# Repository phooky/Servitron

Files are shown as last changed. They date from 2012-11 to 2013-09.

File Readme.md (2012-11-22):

Servitron Six
=============

Servitron Six is a six-axis DC servo control board initially developed to support PUMA robot arms and their cousins. It presumes that each servo consists of a DC gearmotor, a quadrature encoder, and optionally an index channel. It uses a BeagleBone A5 or greater to control the system and is designed so that your application can run directly on the BeagleBone.

It has not yet been tested with the new BeagleBone Black.

Hardware
--------

The board is designed to run off a 24V power supply. A switching supply provides 5V to the logic chips and the BeagleBone. Each servo channel is driven by a VNH3SP30 which can provide a peak of ~20A.

The hardware design files are in the "electronics/six_axis_board" directory. The hardware is licenced under the CERN Open Hardware License v1.1.

Software
--------

The software which runs on the BeagleBone is in the "servitron" directory.

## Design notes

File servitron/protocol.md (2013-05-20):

Servitron client-server protocol
================================

Server responsibilities:
* Track quadrature encoders
* Maintain information about position and velocity of all axes
* Execute positioning/velocity commands
* Maintain PID loops and current position
* Maintain brake

Types of interaction
--------------------

* Hello: client should connect to server and get a greeting message including server version
* Status: client can request status from the server and get current positions, speeds, and queue status.
* Calibration: set PID settings, find index pulse, confirm directionality, find physical range
* Configuration persistence.
* Non-blocking motion commands: clients should be able to place motions on a queue of sequentially interpreted commands

General command/response framework
----------------------------------

Most commands are fixed-length and determined by a simple struct. Commands begin with a one-byte command identifier.
Responses are also generally fixed-length and delivered as soon as possible. They begin with a one-byte response code.

All command-response transactions are sequential; a second command should not be sent before a reply is received unless the response has timed out. Responses delivered more than half a second after the command is sent are considered to have timed out.

Any command or response that is not fixed-length must end in a zero-terminated string.

Response codes
--------------
0x80 - OK
0x81 - generic error

Hello interaction
-----------------

The HELLO interaction is generally sent when a client connects. It is not required.

Command code: 0x01
Command payload:
    uint16_t clientVersion;
    char* clientString;

Response payload:
    uint16_t serverVersion;
    char* serverString;

Status interactions
-------------------

*Mechanical status*
Command code: 0x02
Command payload: None
Response payload:
    {
        int32_t position
        int32_t velocity
        uint8_t flags _axis enabled, axis calibrated, etc_
    }[6]
    uint8_t flags _brake enabled, system initialized_

*Queue status*
Command code: 0x03
Command payload: None
Response payload:
    int16_t remainingMoves

Calibration interactions
------------------------
Calibration and configuration commands begin at 0x10

*Find directionality*
Command code: 0x10
Command payload:
    uint8_t axis
Response payload:
    uint8_t directionality
Directionality response:
* 0x00: directionality is positive (+motor is +pos)
* 0x01: directionality is negative (+motor is -pos)
* 0x02: directionality seek failed (unable to move motor within window)

*Start range of motion seek*
Command code: 0x11
Command payload:
    uint8_t axis
Response payload: None

*Complete range of motion seek*
Command code: 0x12
Command payload: None
Response payload:
    int32_t min_pos
    int32_t max_pos
    // index pulse frequency information??? TODO

*Set PID*
Command code: 0x13
Command payload: 
    uint8_t axis
    // PID data??? TODO
Response payload: None

Persistence interactions
------------------------

*Load config*

*Save config*

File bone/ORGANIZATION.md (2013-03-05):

Yeah, clearly a cleanup is in order. 

Pinmuxing should be centralized, naming should be fixed...

Runtime organization.

Two components: userspace and PRU.

PRU: records quadrature; emits events.

SHOULD: pop out reports, eat settings?

let's do all motor control in userspace for now; we're not going to
beat that speed anyway

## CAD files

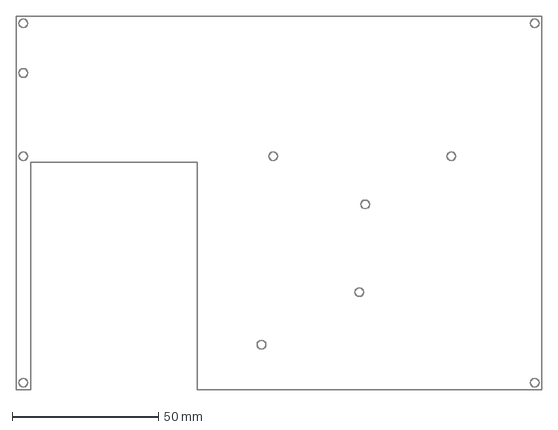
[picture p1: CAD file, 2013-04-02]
electronics/six_axis_board/mounting.dxf
180.0 x 128.0 mm

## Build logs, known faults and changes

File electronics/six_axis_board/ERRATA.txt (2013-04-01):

Version Zero
------------

- The brake transistor is turned on at startup. The bone needs to be initialized properly (appears to be pulling pin low).
- R43 needs to be below 1K to turn on the transistor fully. Not sure what's going on here.
- The brake circuit should be reworked completely.

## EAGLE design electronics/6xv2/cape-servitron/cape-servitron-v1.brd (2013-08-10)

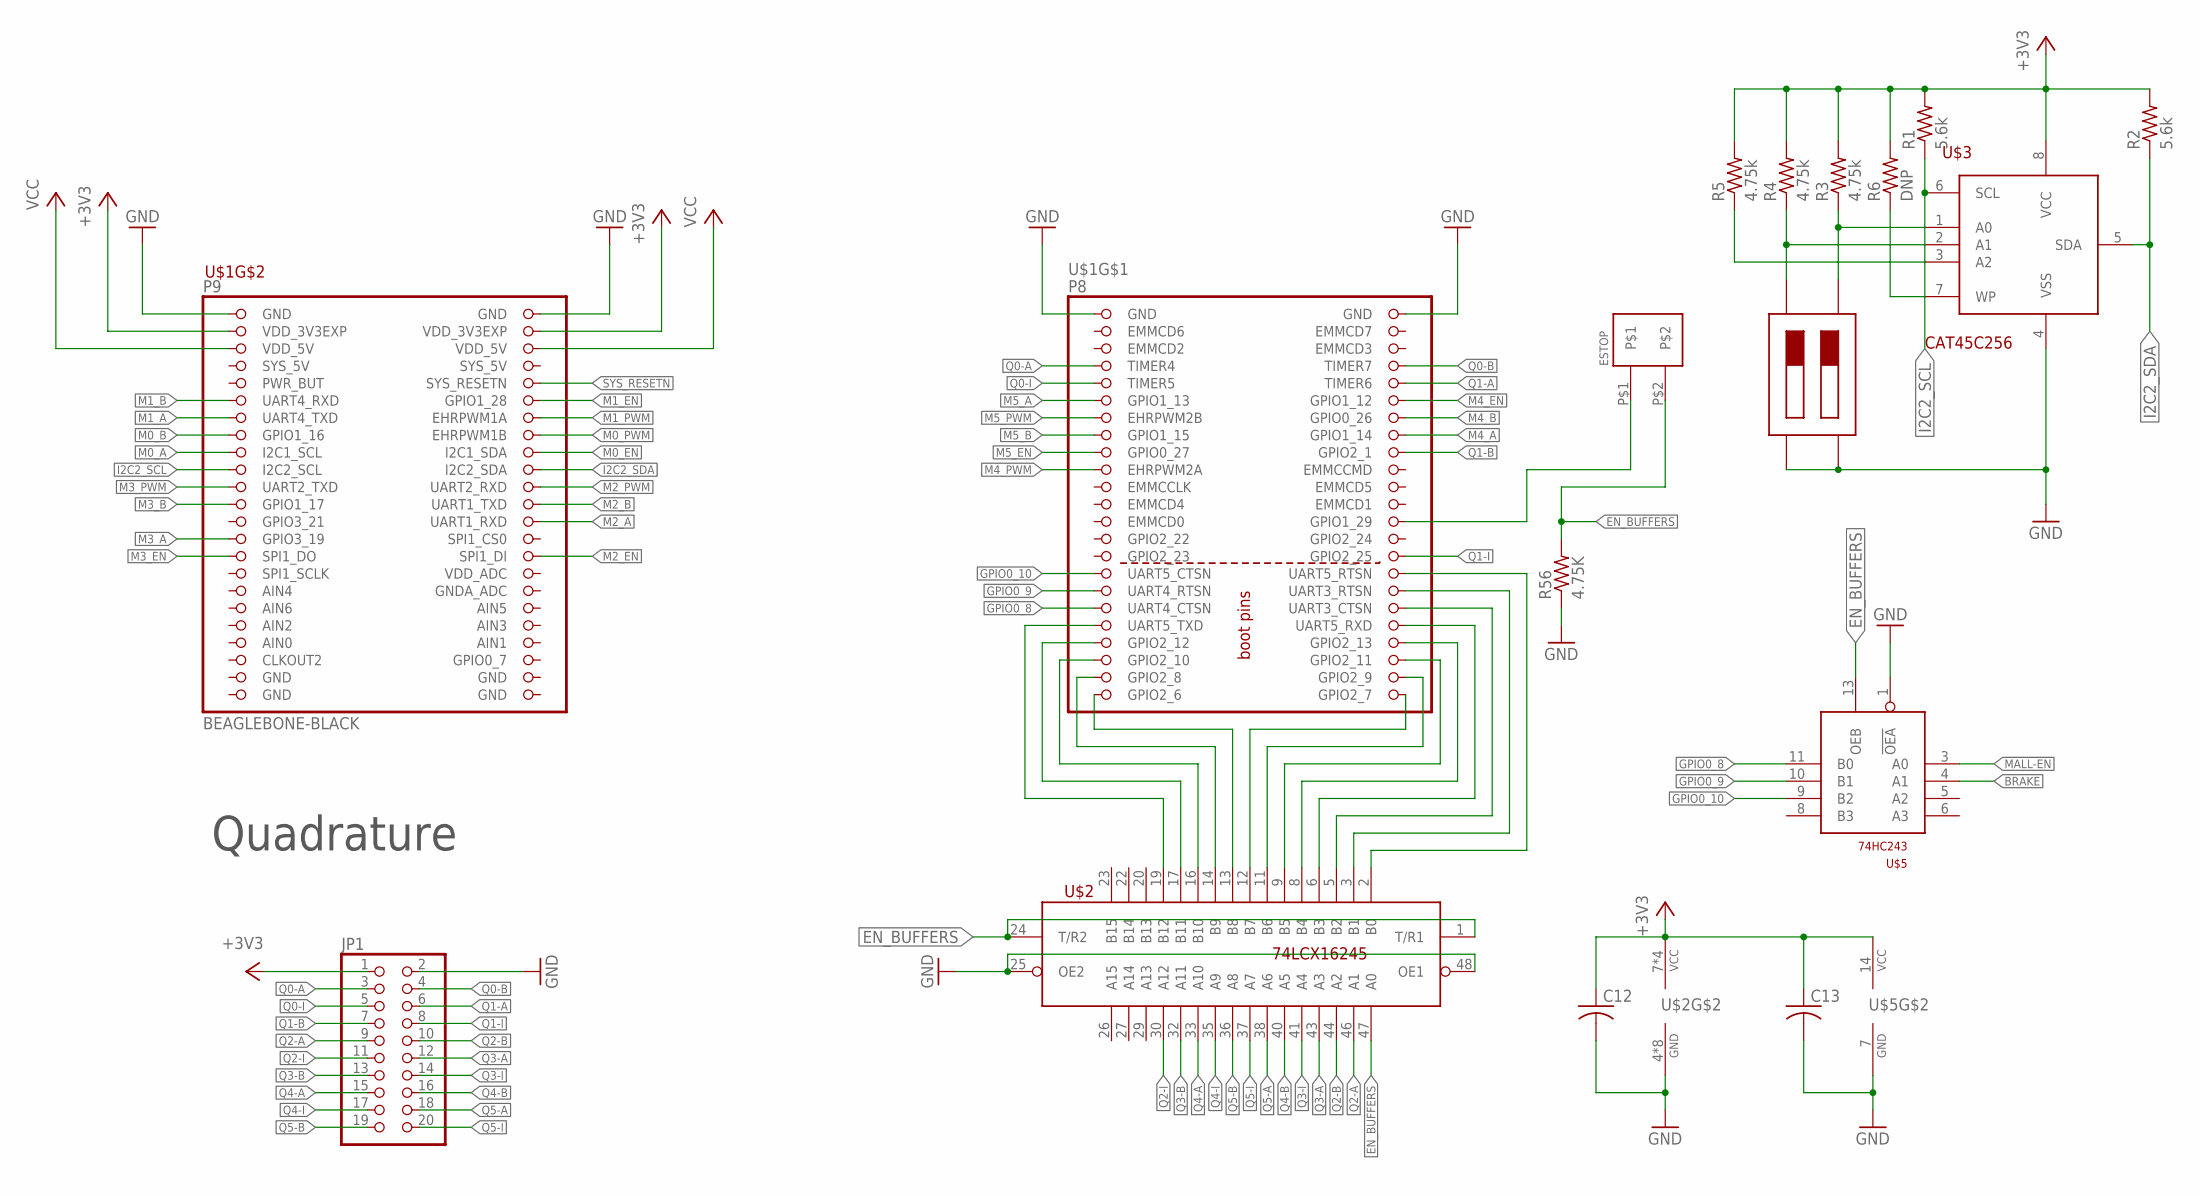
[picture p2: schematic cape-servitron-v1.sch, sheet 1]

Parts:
C12, C13: C-USC0805; C0805
ESTOP: PINHEAD-5MM-1X2; 5MM-HEADER-2
JP1: PINHD-2X10; 2X10
R1, R2: 5.6k; R0805
R3, R4, R5: 4.75k; R0805
R6: DNP; R0805
R56: 4.75K; R0805
U$1: BEAGLEBONE-BLACK; BEAGLEBONE_SHIELD
U$2: 74LCX16245; TSSOP-48
U$3: CAT24C2256Y; TSSOP-8
U$4: DIP-SW-2; CT219-2
U$5: 74HC243D; SO14

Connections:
!MALL-EN: U$5.3 (A0); also elsewhere on the board
+3V3: C12.1, C13.1, JP1.1, R1.2, R2.2, R3.2, R4.2, R5.2, R6.2, U$1.49 (VDD_3V3EXP), U$1.50 (VDD_3V3EXP), U$2.7 (VCC), U$2.18 (VCC), U$2.31 (VCC), U$2.42 (VCC), U$3.8 (VCC), U$5.14 (VCC); also elsewhere on the board
BRAKE: U$5.4 (A1); also elsewhere on the board
EN_BUFFERS: ESTOP.P$2, R56.2, U$2.1 (T/R1), U$2.24 (T/R2), U$2.47 (A0), U$5.13 (OEB)
GND: C12.2, C13.2, JP1.2, R56.1, U$1.1 (GND), U$1.2 (GND), U$1.47 (GND), U$1.48 (GND), U$1.89 (GND), U$1.90 (GND), U$1.91 (GND), U$1.92 (GND), U$2.4 (GND), U$2.10 (GND), U$2.15 (GND), U$2.21 (GND), U$2.25 (OE2), U$2.28 (GND), U$2.34 (GND), U$2.39 (GND), U$2.45 (GND), U$2.48 (OE1), U$3.4 (VSS), U$4.1, U$4.2, U$5.1 (!OEA), U$5.7 (GND); also elsewhere on the board
GPIO0_8: U$1.35 (UART4_CTSN), U$5.11 (B0)
GPIO0_9: U$1.33 (UART4_RTSN), U$5.10 (B1)
GPIO0_10: U$1.31 (UART5_CTSN), U$5.9 (B2)
I2C2_SCL: R1.1, U$1.65 (I2C2_SCL), U$3.6 (SCL)
I2C2_SDA: R2.1, U$1.66 (I2C2_SDA), U$3.5 (SDA)
M0_A: U$1.63 (I2C1_SCL); also elsewhere on the board
M0_B: U$1.61 (GPIO1_16); also elsewhere on the board
M0_EN: U$1.64 (I2C1_SDA); also elsewhere on the board
M0_PWM: U$1.62 (EHRPWM1B); also elsewhere on the board
M1_A: U$1.59 (UART4_TXD); also elsewhere on the board
M1_B: U$1.57 (UART4_RXD); also elsewhere on the board
M1_EN: U$1.58 (GPIO1_28); also elsewhere on the board
M1_PWM: U$1.60 (EHRPWM1A); also elsewhere on the board
M2_A: U$1.72 (UART1_RXD); also elsewhere on the board
M2_B: U$1.70 (UART1_TXD); also elsewhere on the board
M2_EN: U$1.76 (SPI1_DI); also elsewhere on the board
M2_PWM: U$1.68 (UART2_RXD); also elsewhere on the board
M3_A: U$1.73 (GPIO3_19); also elsewhere on the board
M3_B: U$1.69 (GPIO1_17); also elsewhere on the board
M3_EN: U$1.75 (SPI1_DO); also elsewhere on the board
M3_PWM: U$1.67 (UART2_TXD); also elsewhere on the board
M4_A: U$1.16 (GPIO1_14); also elsewhere on the board
M4_B: U$1.14 (GPIO0_26); also elsewhere on the board
M4_EN: U$1.12 (GPIO1_12); also elsewhere on the board
M4_PWM: U$1.19 (EHRPWM2A); also elsewhere on the board
M5_A: U$1.11 (GPIO1_13); also elsewhere on the board
M5_B: U$1.15 (GPIO1_15); also elsewhere on the board
M5_EN: U$1.17 (GPIO0_27); also elsewhere on the board
M5_PWM: U$1.13 (EHRPWM2B); also elsewhere on the board
unnamed: U$1.45 (GPIO2_6), U$2.13 (B8)
unnamed: U$1.46 (GPIO2_7), U$2.12 (B7)
unnamed: U$1.43 (GPIO2_8), U$2.14 (B9)
unnamed: U$1.44 (GPIO2_9), U$2.11 (B6)
unnamed: U$1.41 (GPIO2_10), U$2.16 (B10)
unnamed: U$1.42 (GPIO2_11), U$2.9 (B5)
unnamed: U$1.40 (GPIO2_13), U$2.8 (B4)
unnamed: U$1.39 (GPIO2_12), U$2.17 (B11)
unnamed: U$1.37 (UART5_TXD), U$2.19 (B12)
unnamed: U$1.38 (UART5_RXD), U$2.6 (B3)
unnamed: U$1.36 (UART3_CTSN), U$2.5 (B2)
unnamed: U$1.34 (UART3_RTSN), U$2.3 (B1)
unnamed: R3.1, U$3.1 (A0), U$4.4
unnamed: R4.1, U$3.2 (A1), U$4.3
unnamed: R5.1, U$3.3 (A2)
unnamed: R6.1, U$3.7 (WP)
unnamed: U$1.32 (UART5_RTSN), U$2.2 (B0)
unnamed: ESTOP.P$1, U$1.26 (GPIO1_29)
Q0-A: JP1.3, U$1.7 (TIMER4)
Q0-B: JP1.4, U$1.8 (TIMER7)
Q0-I: JP1.5, U$1.9 (TIMER5)
Q1-A: JP1.6, U$1.10 (TIMER6)
Q1-B: JP1.7, U$1.18 (GPIO2_1)
Q1-I: JP1.8, U$1.30 (GPIO2_25)
Q2-A: JP1.9, U$2.46 (A1)
Q2-B: JP1.10, U$2.44 (A2)
Q2-I: JP1.11, U$2.30 (A12)
Q3-A: JP1.12, U$2.43 (A3)
Q3-B: JP1.13, U$2.32 (A11)
Q3-I: JP1.14, U$2.41 (A4)
Q4-A: JP1.15, U$2.33 (A10)
Q4-B: JP1.16, U$2.40 (A5)
Q4-I: JP1.17, U$2.35 (A9)
Q5-A: JP1.18, U$2.38 (A6)
Q5-B: JP1.19, U$2.36 (A8)
Q5-I: JP1.20, U$2.37 (A7)
SYS_RESETN: U$1.56 (SYS_RESETN)
VCC: U$1.51 (VDD_5V), U$1.52 (VDD_5V); also elsewhere on the board

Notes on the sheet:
Quadrature

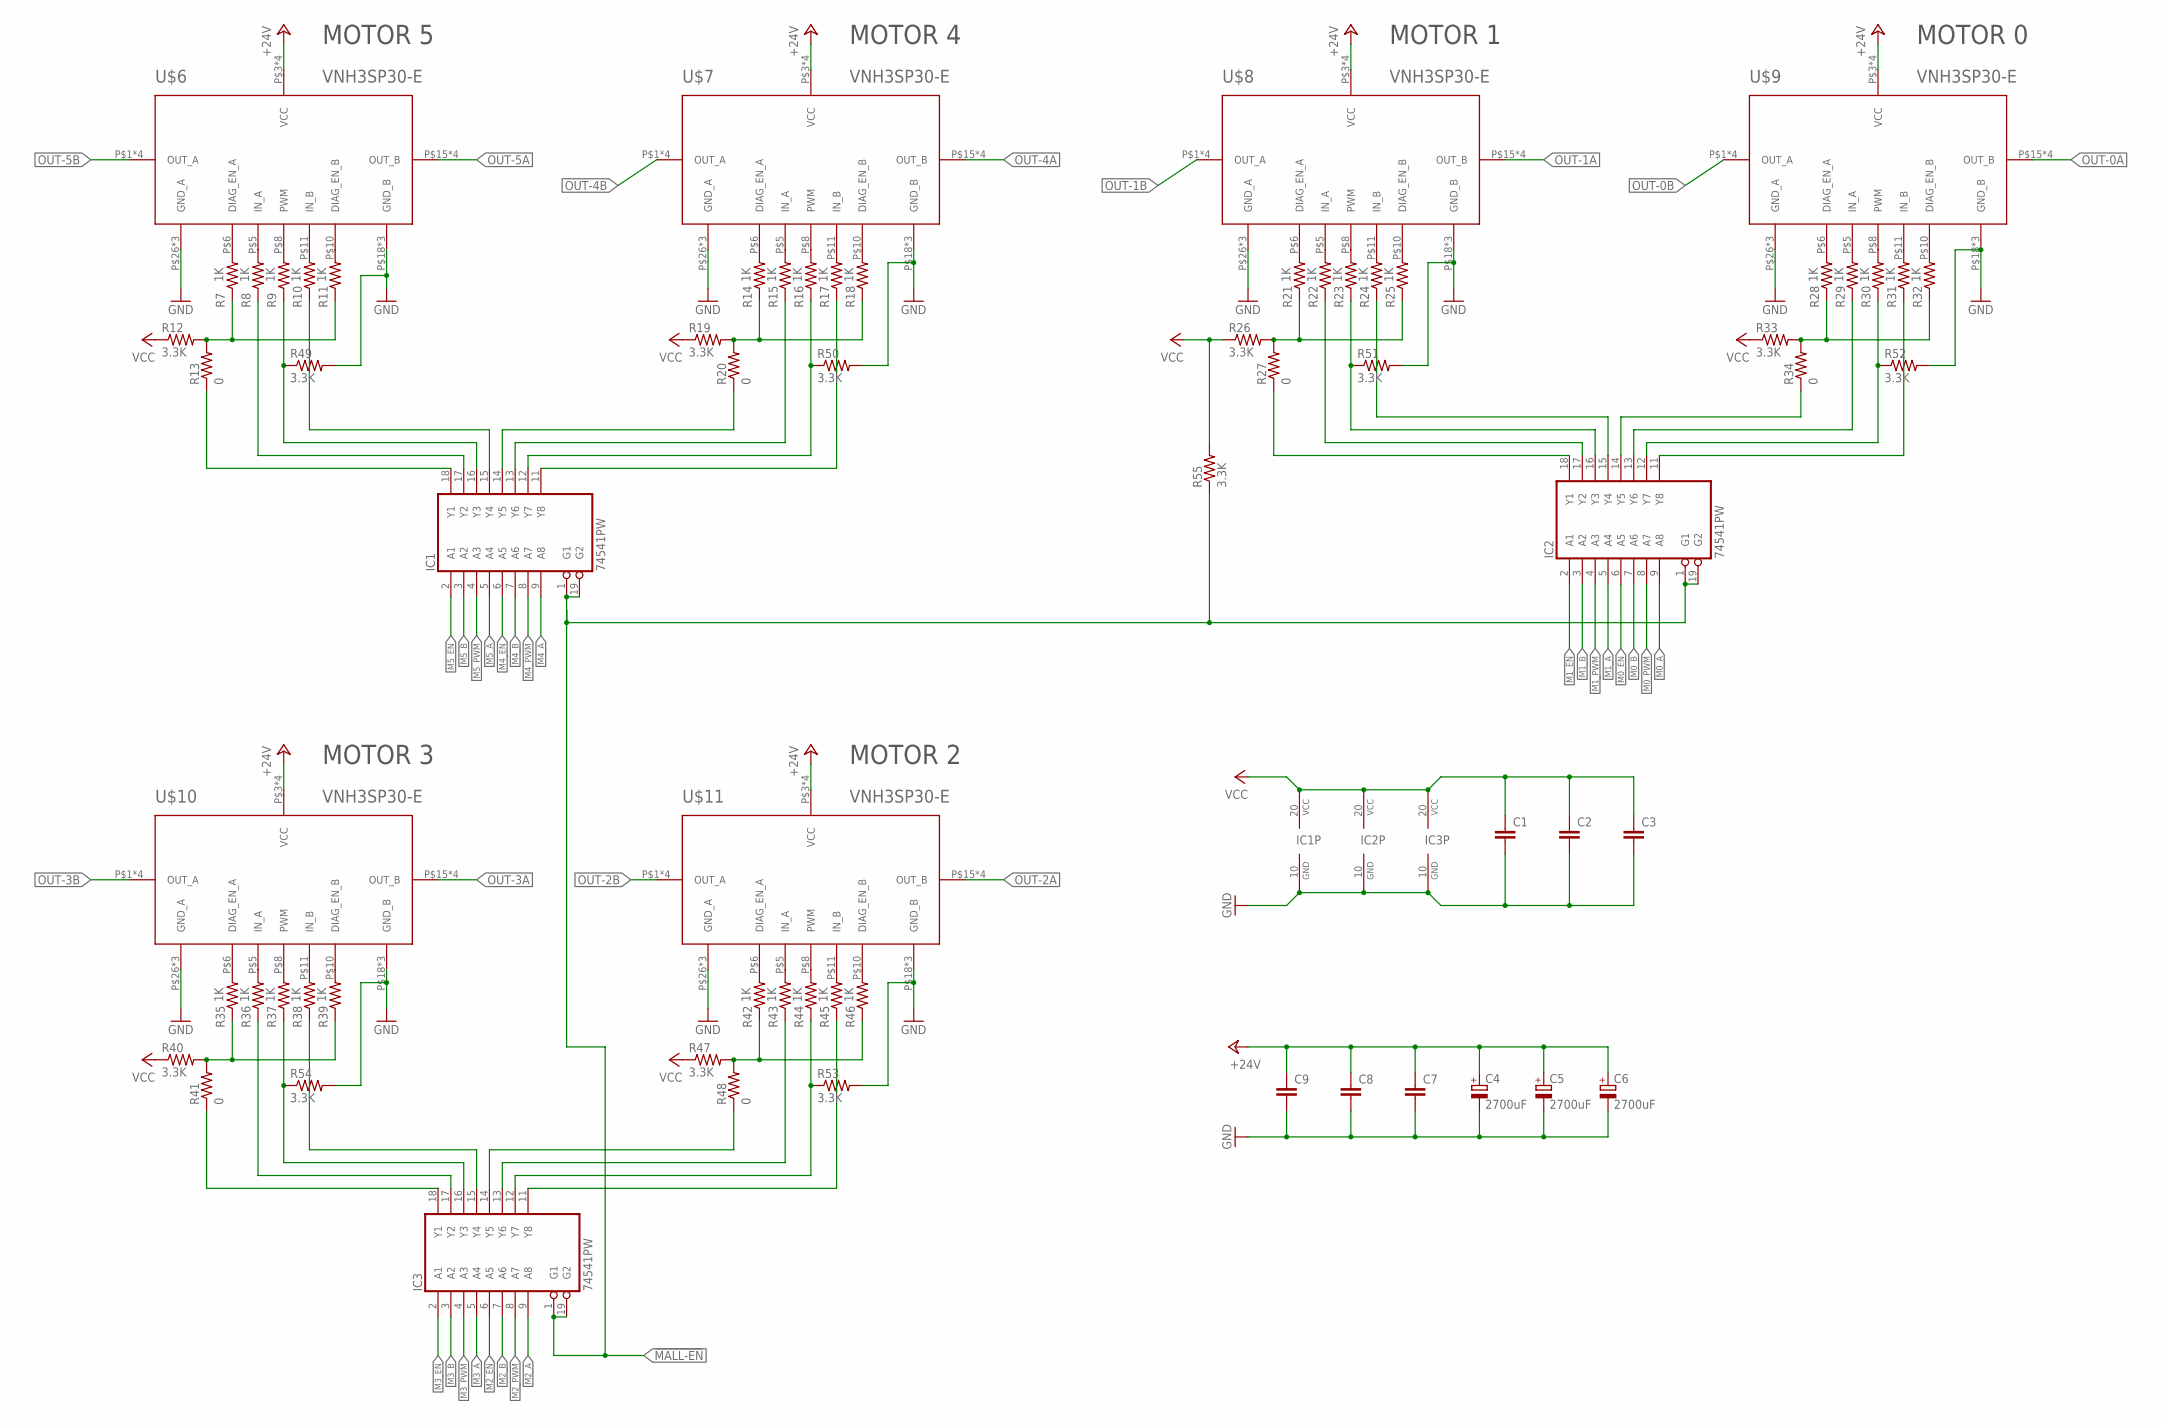
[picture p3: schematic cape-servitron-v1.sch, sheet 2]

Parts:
C1, C2, C3, C7, C8, C9: C-EUC1206; C1206
C4, C5, C6: 2700uF; E5-13
IC1, IC2, IC3: 74541PW; TSSOP-20
R7, R8, R9, R10, R11, R14, R15, R16, R17, R18, R21, R22, R23, R24, R25, R28, R29, R30, R31, R32, R35, R36, R37, R38, R39, R42, R43, R44, R45, R46: 1K; R0805
R12, R19, R26, R33, R40, R47, R49, R50, R51, R52, R53, R54, R55: 3.3K; R0805
R13, R20, R27, R34, R41, R48: 0; R0805
U$6, U$7, U$8, U$9, U$10, U$11: VNH3SP30-E; MULTIPOWER-SO-30

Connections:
!MALL-EN: IC1.1 (G1), IC1.19 (G2), IC2.1 (G1), IC2.19 (G2), IC3.1 (G1), IC3.19 (G2), R55.1; also elsewhere on the board
+24V: C4.+, C5.+, C6.+, C7.1, C8.1, C9.1, U$6.P$3 (VCC), U$6.P$13 (VCC), U$6.P$23 (VCC), U$6.T$3 (VCC), U$7.P$3 (VCC), U$7.P$13 (VCC), U$7.P$23 (VCC), U$7.T$3 (VCC), U$8.P$3 (VCC), U$8.P$13 (VCC), U$8.P$23 (VCC), U$8.T$3 (VCC), U$9.P$3 (VCC), U$9.P$13 (VCC), U$9.P$23 (VCC), U$9.T$3 (VCC), U$10.P$3 (VCC), U$10.P$13 (VCC), U$10.P$23 (VCC), U$10.T$3 (VCC), U$11.P$3 (VCC), U$11.P$13 (VCC), U$11.P$23 (VCC), U$11.T$3 (VCC); also elsewhere on the board
GND: C1.2, C2.2, C3.2, C4.-, C5.-, C6.-, C7.2, C8.2, C9.2, IC1.10 (GND), IC2.10 (GND), IC3.10 (GND), R49.2, R50.2, R51.2, R52.2, R53.2, R54.2, U$6.P$18 (GND_B), U$6.P$19 (GND_B), U$6.P$20 (GND_B), U$6.P$26 (GND_A), U$6.P$27 (GND_A), U$6.P$28 (GND_A), U$7.P$18 (GND_B), U$7.P$19 (GND_B), U$7.P$20 (GND_B), U$7.P$26 (GND_A), U$7.P$27 (GND_A), U$7.P$28 (GND_A), U$8.P$18 (GND_B), U$8.P$19 (GND_B), U$8.P$20 (GND_B), U$8.P$26 (GND_A), U$8.P$27 (GND_A), U$8.P$28 (GND_A), U$9.P$18 (GND_B), U$9.P$19 (GND_B), U$9.P$20 (GND_B), U$9.P$26 (GND_A), U$9.P$27 (GND_A), U$9.P$28 (GND_A), U$10.P$18 (GND_B), U$10.P$19 (GND_B), U$10.P$20 (GND_B), U$10.P$26 (GND_A), U$10.P$27 (GND_A), U$10.P$28 (GND_A), U$11.P$18 (GND_B), U$11.P$19 (GND_B), U$11.P$20 (GND_B), U$11.P$26 (GND_A), U$11.P$27 (GND_A), U$11.P$28 (GND_A); also elsewhere on the board
M0_A: IC2.9 (A8); also elsewhere on the board
M0_B: IC2.7 (A6); also elsewhere on the board
M0_EN: IC2.6 (A5); also elsewhere on the board
M0_PWM: IC2.8 (A7); also elsewhere on the board
M1_A: IC2.5 (A4); also elsewhere on the board
M1_B: IC2.3 (A2); also elsewhere on the board
M1_EN: IC2.2 (A1); also elsewhere on the board
M1_PWM: IC2.4 (A3); also elsewhere on the board
M2_A: IC3.9 (A8); also elsewhere on the board
M2_B: IC3.7 (A6); also elsewhere on the board
M2_EN: IC3.6 (A5); also elsewhere on the board
M2_PWM: IC3.8 (A7); also elsewhere on the board
M3_A: IC3.5 (A4); also elsewhere on the board
M3_B: IC3.3 (A2); also elsewhere on the board
M3_EN: IC3.2 (A1); also elsewhere on the board
M3_PWM: IC3.4 (A3); also elsewhere on the board
M4_A: IC1.9 (A8); also elsewhere on the board
M4_B: IC1.7 (A6); also elsewhere on the board
M4_EN: IC1.6 (A5); also elsewhere on the board
M4_PWM: IC1.8 (A7); also elsewhere on the board
M5_A: IC1.5 (A4); also elsewhere on the board
M5_B: IC1.3 (A2); also elsewhere on the board
M5_EN: IC1.2 (A1); also elsewhere on the board
M5_PWM: IC1.4 (A3); also elsewhere on the board
unnamed: R7.2, U$6.P$6 (DIAG_EN_A)
unnamed: R7.1, R11.1, R12.2, R13.2
unnamed: IC1.18 (Y1), R13.1
unnamed: IC1.17 (Y2), R8.1
unnamed: IC1.16 (Y3), R9.1, R49.1
unnamed: IC1.15 (Y4), R10.1
unnamed: R8.2, U$6.P$5 (IN_A)
unnamed: R9.2, U$6.P$8 (PWM)
unnamed: R10.2, U$6.P$11 (IN_B)
unnamed: R11.2, U$6.P$10 (DIAG_EN_B)
unnamed: R14.2, U$7.P$6 (DIAG_EN_A)
unnamed: R14.1, R18.1, R19.2, R20.2
unnamed: IC1.11 (Y8), R17.1
unnamed: IC1.12 (Y7), R16.1, R50.1
unnamed: IC1.13 (Y6), R15.1
unnamed: IC1.14 (Y5), R20.1
unnamed: R21.2, U$8.P$6 (DIAG_EN_A)
unnamed: R21.1, R25.1, R26.2, R27.2
unnamed: IC2.18 (Y1), R27.1
unnamed: IC2.17 (Y2), R22.1
unnamed: IC2.16 (Y3), R23.1, R51.1
unnamed: IC2.15 (Y4), R24.1
unnamed: R22.2, U$8.P$5 (IN_A)
unnamed: R23.2, U$8.P$8 (PWM)
unnamed: R24.2, U$8.P$11 (IN_B)
unnamed: R25.2, U$8.P$10 (DIAG_EN_B)
unnamed: R28.2, U$9.P$6 (DIAG_EN_A)
unnamed: R28.1, R32.1, R33.2, R34.2
unnamed: IC2.11 (Y8), R31.1
unnamed: IC2.12 (Y7), R30.1, R52.1
unnamed: IC2.13 (Y6), R29.1
unnamed: IC2.14 (Y5), R34.1
unnamed: R35.2, U$10.P$6 (DIAG_EN_A)
unnamed: R35.1, R39.1, R40.2, R41.2
unnamed: IC3.18 (Y1), R41.1
unnamed: IC3.11 (Y8), R45.1
unnamed: IC3.17 (Y2), R36.1
unnamed: IC3.16 (Y3), R37.1, R54.1
unnamed: R36.2, U$10.P$5 (IN_A)
unnamed: R37.2, U$10.P$8 (PWM)
unnamed: R38.2, U$10.P$11 (IN_B)
unnamed: R39.2, U$10.P$10 (DIAG_EN_B)
unnamed: R42.2, U$11.P$6 (DIAG_EN_A)
unnamed: R42.1, R46.1, R47.2, R48.2
unnamed: IC3.15 (Y4), R38.1
unnamed: IC3.12 (Y7), R44.1, R53.1
unnamed: IC3.13 (Y6), R43.1
unnamed: IC3.14 (Y5), R48.1
unnamed: R45.2, U$11.P$11 (IN_B)
unnamed: R44.2, U$11.P$8 (PWM)
unnamed: R43.2, U$11.P$5 (IN_A)
unnamed: R46.2, U$11.P$10 (DIAG_EN_B)
unnamed: R18.2, U$7.P$10 (DIAG_EN_B)
unnamed: R17.2, U$7.P$11 (IN_B)
unnamed: R16.2, U$7.P$8 (PWM)
unnamed: R15.2, U$7.P$5 (IN_A)
unnamed: R32.2, U$9.P$10 (DIAG_EN_B)
unnamed: R31.2, U$9.P$11 (IN_B)
unnamed: R30.2, U$9.P$8 (PWM)
unnamed: R29.2, U$9.P$5 (IN_A)
OUT-0A: U$9.P$15 (OUT_B), U$9.P$16 (OUT_B), U$9.P$21 (OUT_B), U$9.T$2 (OUT_B); also elsewhere on the board
OUT-0B: U$9.P$1 (OUT_A), U$9.P$25 (OUT_A), U$9.P$30 (OUT_A), U$9.T$1 (OUT_A); also elsewhere on the board
OUT-1A: U$8.P$15 (OUT_B), U$8.P$16 (OUT_B), U$8.P$21 (OUT_B), U$8.T$2 (OUT_B); also elsewhere on the board
OUT-1B: U$8.P$1 (OUT_A), U$8.P$25 (OUT_A), U$8.P$30 (OUT_A), U$8.T$1 (OUT_A); also elsewhere on the board
OUT-2A: U$11.P$15 (OUT_B), U$11.P$16 (OUT_B), U$11.P$21 (OUT_B), U$11.T$2 (OUT_B); also elsewhere on the board
OUT-2B: U$11.P$1 (OUT_A), U$11.P$25 (OUT_A), U$11.P$30 (OUT_A), U$11.T$1 (OUT_A); also elsewhere on the board
OUT-3A: U$10.P$15 (OUT_B), U$10.P$16 (OUT_B), U$10.P$21 (OUT_B), U$10.T$2 (OUT_B); also elsewhere on the board
OUT-3B: U$10.P$1 (OUT_A), U$10.P$25 (OUT_A), U$10.P$30 (OUT_A), U$10.T$1 (OUT_A); also elsewhere on the board
OUT-4A: U$7.P$15 (OUT_B), U$7.P$16 (OUT_B), U$7.P$21 (OUT_B), U$7.T$2 (OUT_B); also elsewhere on the board
OUT-4B: U$7.P$1 (OUT_A), U$7.P$25 (OUT_A), U$7.P$30 (OUT_A), U$7.T$1 (OUT_A); also elsewhere on the board
OUT-5A: U$6.P$15 (OUT_B), U$6.P$16 (OUT_B), U$6.P$21 (OUT_B), U$6.T$2 (OUT_B); also elsewhere on the board
OUT-5B: U$6.P$1 (OUT_A), U$6.P$25 (OUT_A), U$6.P$30 (OUT_A), U$6.T$1 (OUT_A); also elsewhere on the board
VCC: C1.1, C2.1, C3.1, IC1.20 (VCC), IC2.20 (VCC), IC3.20 (VCC), R12.1, R19.1, R26.1, R33.1, R40.1, R47.1, R55.2; also elsewhere on the board

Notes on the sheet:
MOTOR 5
MOTOR 4
MOTOR 1
MOTOR 0
MOTOR 3
MOTOR 2

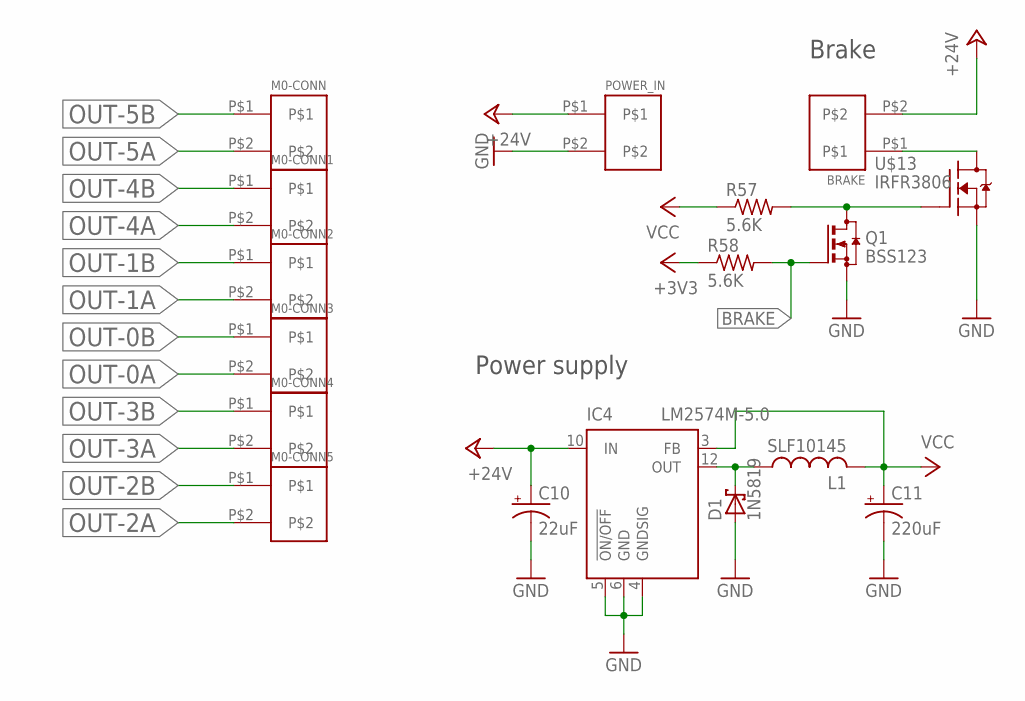
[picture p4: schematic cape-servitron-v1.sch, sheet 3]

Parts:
BRAKE: PINHEAD-5MM-1X2; 5MM-HEADER-2
C10: 22uF; SANYO-OSCON_SMD_E7
C11: 220uF; SANYO-OSCON_SMD_F8
D1: 1N5819; SOD-123
IC4: LM2574M-5.0; SO14W
L1: SLF10145; SMD10145
M0-CONN, M0-CONN1, M0-CONN2, M0-CONN3, M0-CONN4, M0-CONN5: PINHEAD-5MM-1X2; 5MM-HEADER-2
POWER_IN: PINHEAD-5MM-1X2; 5MM-HEADER-2
Q1: BSS123; SOT23
R57, R58: 5.6K; R0805
U$13: IRFR3806; TO252

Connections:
+3V3: R58.1; also elsewhere on the board
+24V: BRAKE.P$2, C10.+, IC4.10 (IN), POWER_IN.P$1; also elsewhere on the board
BRAKE: Q1.1 (G), R58.2; also elsewhere on the board
GND: C10.-, C11.-, D1.A, IC4.4 (GNDSIG), IC4.5 (!ON/OFF), IC4.6 (GND), POWER_IN.P$2, Q1.2 (S), U$13.2 (S); also elsewhere on the board
unnamed: D1.C, IC4.12 (OUT), L1.P$1 (1)
unnamed: BRAKE.P$1, U$13.3 (D)
unnamed: Q1.3 (D), R57.2, U$13.1 (G)
OUT-0A: M0-CONN3.P$2; also elsewhere on the board
OUT-0B: M0-CONN3.P$1; also elsewhere on the board
OUT-1A: M0-CONN2.P$2; also elsewhere on the board
OUT-1B: M0-CONN2.P$1; also elsewhere on the board
OUT-2A: M0-CONN5.P$2; also elsewhere on the board
OUT-2B: M0-CONN5.P$1; also elsewhere on the board
OUT-3A: M0-CONN4.P$2; also elsewhere on the board
OUT-3B: M0-CONN4.P$1; also elsewhere on the board
OUT-4A: M0-CONN1.P$2; also elsewhere on the board
OUT-4B: M0-CONN1.P$1; also elsewhere on the board
OUT-5A: M0-CONN.P$2; also elsewhere on the board
OUT-5B: M0-CONN.P$1; also elsewhere on the board
VCC: C11.+, IC4.3 (FB), L1.P$2 (2), R57.1; also elsewhere on the board

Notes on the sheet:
Power supply
Brake

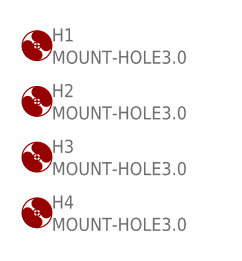
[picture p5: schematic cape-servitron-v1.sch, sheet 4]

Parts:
H1, H2, H3, H4: MOUNT-HOLE3.0; 3,0

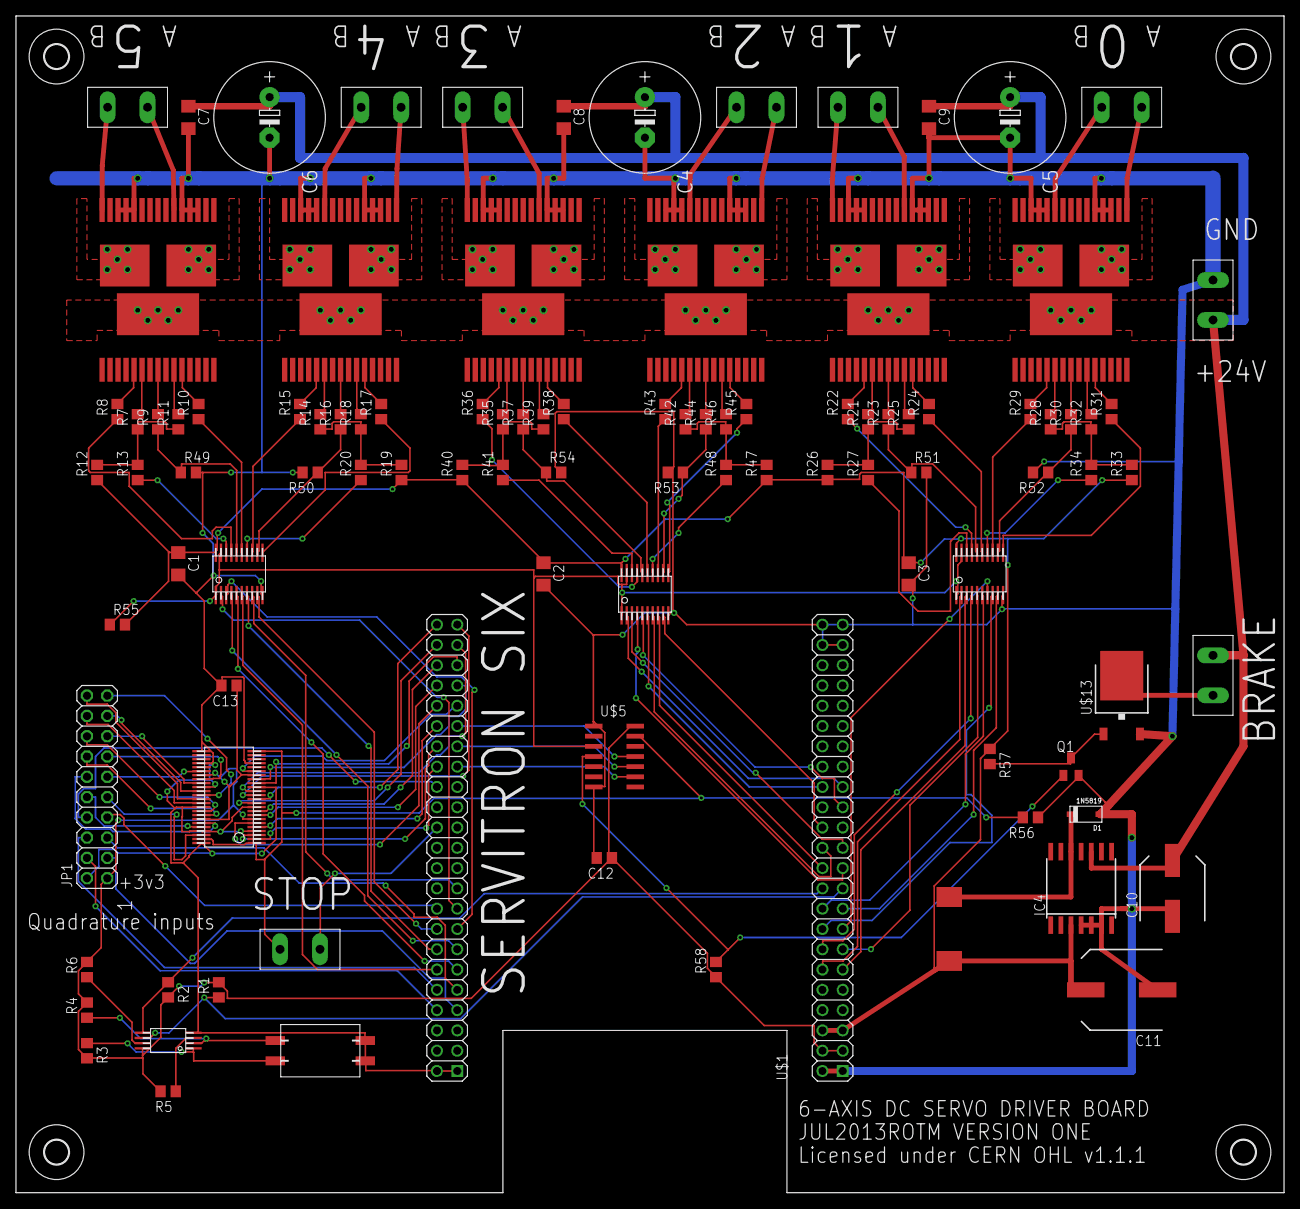
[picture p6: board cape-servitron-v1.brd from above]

Board: 2 copper layers, 158.8 x 147.3 mm, 104 parts (0 on the bottom side), 147 nets.

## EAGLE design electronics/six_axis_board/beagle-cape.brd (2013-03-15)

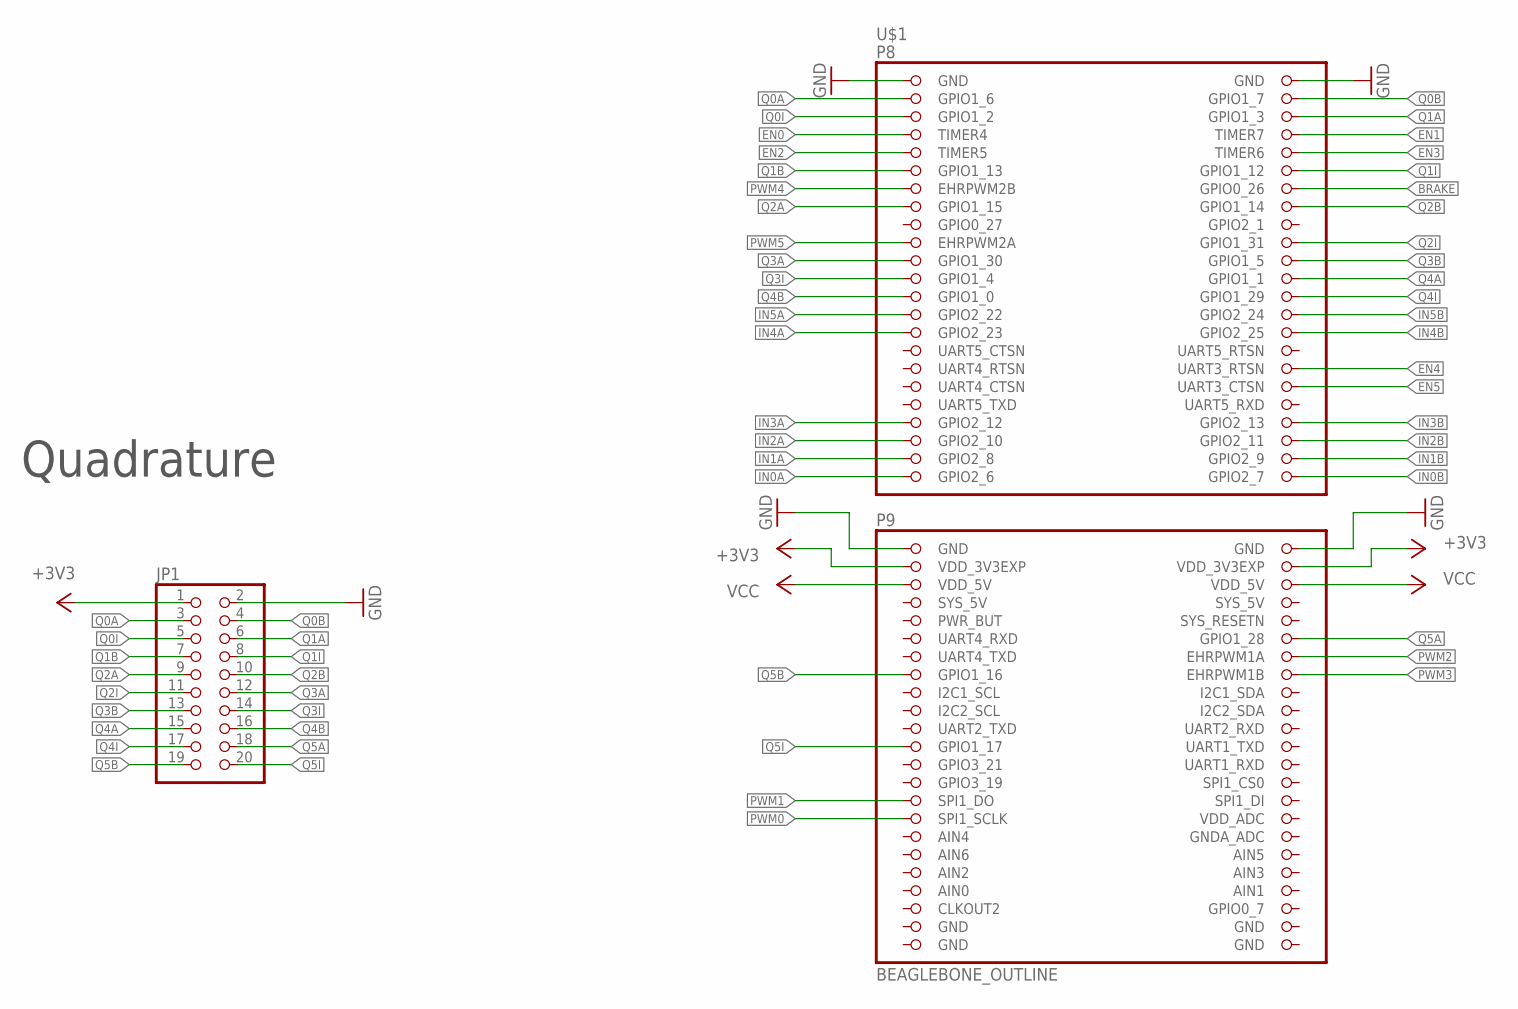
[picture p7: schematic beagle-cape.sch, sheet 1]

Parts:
JP1: PINHD-2X10; 2X10
U$1: BEAGLEBONE_OUTLINE; BEAGLEBONE_SHIELD

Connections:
+3V3: JP1.1, U$1.49 (VDD_3V3EXP), U$1.50 (VDD_3V3EXP); also elsewhere on the board
BRAKE: U$1.14 (GPIO0_26); also elsewhere on the board
EN0: U$1.7 (TIMER4); also elsewhere on the board
EN1: U$1.8 (TIMER7); also elsewhere on the board
EN2: U$1.9 (TIMER5); also elsewhere on the board
EN3: U$1.10 (TIMER6); also elsewhere on the board
EN4: U$1.34 (UART3_RTSN); also elsewhere on the board
EN5: U$1.36 (UART3_CTSN); also elsewhere on the board
GND: JP1.2, U$1.1 (GND), U$1.2 (GND), U$1.47 (GND), U$1.48 (GND), U$1.89 (GND), U$1.90 (GND), U$1.91 (GND), U$1.92 (GND); also elsewhere on the board
IN0A: U$1.45 (GPIO2_6); also elsewhere on the board
IN0B: U$1.46 (GPIO2_7); also elsewhere on the board
IN1A: U$1.43 (GPIO2_8); also elsewhere on the board
IN1B: U$1.44 (GPIO2_9); also elsewhere on the board
IN2A: U$1.41 (GPIO2_10); also elsewhere on the board
IN2B: U$1.42 (GPIO2_11); also elsewhere on the board
IN3A: U$1.39 (GPIO2_12); also elsewhere on the board
IN3B: U$1.40 (GPIO2_13); also elsewhere on the board
IN4A: U$1.29 (GPIO2_23); also elsewhere on the board
IN4B: U$1.30 (GPIO2_25); also elsewhere on the board
IN5A: U$1.27 (GPIO2_22); also elsewhere on the board
IN5B: U$1.28 (GPIO2_24); also elsewhere on the board
PWM0: U$1.77 (SPI1_SCLK); also elsewhere on the board
PWM1: U$1.75 (SPI1_DO); also elsewhere on the board
PWM2: U$1.60 (EHRPWM1A); also elsewhere on the board
PWM3: U$1.62 (EHRPWM1B); also elsewhere on the board
PWM4: U$1.13 (EHRPWM2B); also elsewhere on the board
PWM5: U$1.19 (EHRPWM2A); also elsewhere on the board
Q0A: JP1.3, U$1.3 (GPIO1_6)
Q0B: JP1.4, U$1.4 (GPIO1_7)
Q0I: JP1.5, U$1.5 (GPIO1_2)
Q1A: JP1.6, U$1.6 (GPIO1_3)
Q1B: JP1.7, U$1.11 (GPIO1_13)
Q1I: JP1.8, U$1.12 (GPIO1_12)
Q2A: JP1.9, U$1.15 (GPIO1_15)
Q2B: JP1.10, U$1.16 (GPIO1_14)
Q2I: JP1.11, U$1.20 (GPIO1_31)
Q3A: JP1.12, U$1.21 (GPIO1_30)
Q3B: JP1.13, U$1.22 (GPIO1_5)
Q3I: JP1.14, U$1.23 (GPIO1_4)
Q4A: JP1.15, U$1.24 (GPIO1_1)
Q4B: JP1.16, U$1.25 (GPIO1_0)
Q4I: JP1.17, U$1.26 (GPIO1_29)
Q5A: JP1.18, U$1.58 (GPIO1_28)
Q5B: JP1.19, U$1.61 (GPIO1_16)
Q5I: JP1.20, U$1.69 (GPIO1_17)
VCC: U$1.51 (VDD_5V), U$1.52 (VDD_5V); also elsewhere on the board

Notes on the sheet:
Quadrature

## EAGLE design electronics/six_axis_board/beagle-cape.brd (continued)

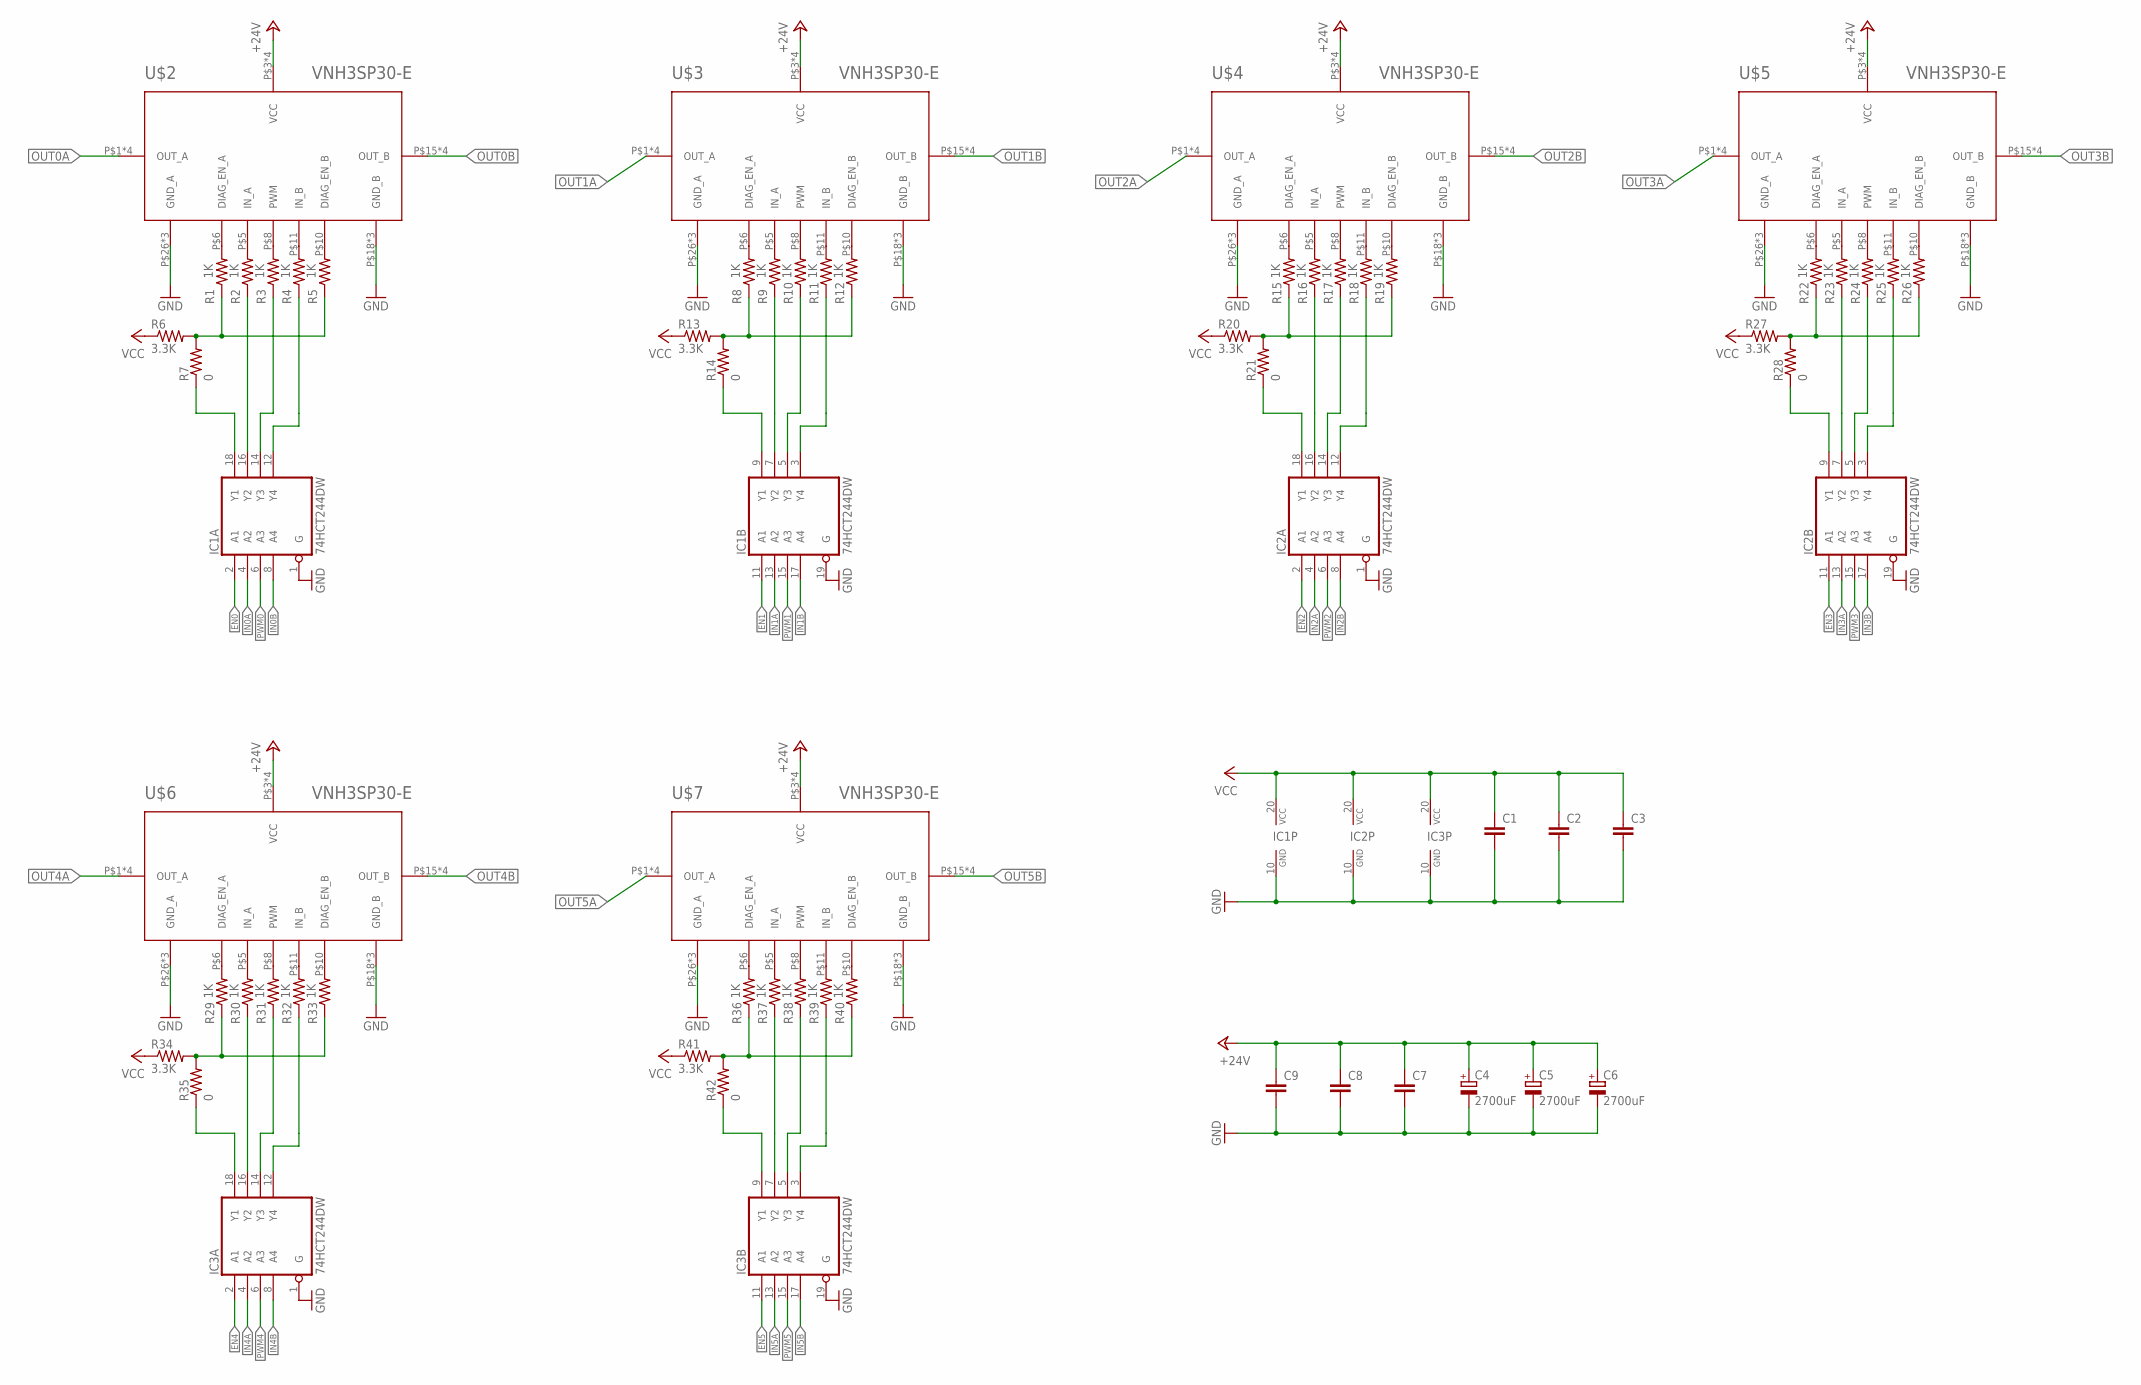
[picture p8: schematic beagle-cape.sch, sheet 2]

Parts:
C1, C2, C3, C7, C8, C9: C-EUC1206; C1206
C4, C5, C6: 2700uF; E5-13
IC1, IC2, IC3: 74HCT244DW; SO20W
R1, R2, R3, R4, R5, R8, R9, R10, R11, R12, R15, R16, R17, R18, R19, R22, R23, R24, R25, R26, R29, R30, R31, R32, R33, R36, R37, R38, R39, R40: 1K; R1206
R6, R13, R20, R27, R34, R41: 3.3K; R1206
R7, R14, R21, R28, R35, R42: 0; R1206
U$2, U$3, U$4, U$5, U$6, U$7: VNH3SP30-E; MULTIPOWER-SO-30

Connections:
+24V: C4.+, C5.+, C6.+, C7.1, C8.1, C9.1, U$2.P$3 (VCC), U$2.P$13 (VCC), U$2.P$23 (VCC), U$2.T$3 (VCC), U$3.P$3 (VCC), U$3.P$13 (VCC), U$3.P$23 (VCC), U$3.T$3 (VCC), U$4.P$3 (VCC), U$4.P$13 (VCC), U$4.P$23 (VCC), U$4.T$3 (VCC), U$5.P$3 (VCC), U$5.P$13 (VCC), U$5.P$23 (VCC), U$5.T$3 (VCC), U$6.P$3 (VCC), U$6.P$13 (VCC), U$6.P$23 (VCC), U$6.T$3 (VCC), U$7.P$3 (VCC), U$7.P$13 (VCC), U$7.P$23 (VCC), U$7.T$3 (VCC); also elsewhere on the board
EN0: IC1.2 (A1); also elsewhere on the board
EN1: IC1.11 (A1); also elsewhere on the board
EN2: IC2.2 (A1); also elsewhere on the board
EN3: IC2.11 (A1); also elsewhere on the board
EN4: IC3.2 (A1); also elsewhere on the board
EN5: IC3.11 (A1); also elsewhere on the board
GND: C1.2, C2.2, C3.2, C4.-, C5.-, C6.-, C7.2, C8.2, C9.2, IC1.1 (G), IC1.10 (GND), IC1.19 (G), IC2.1 (G), IC2.10 (GND), IC2.19 (G), IC3.1 (G), IC3.10 (GND), IC3.19 (G), U$2.P$18 (GND_B), U$2.P$19 (GND_B), U$2.P$20 (GND_B), U$2.P$26 (GND_A), U$2.P$27 (GND_A), U$2.P$28 (GND_A), U$3.P$18 (GND_B), U$3.P$19 (GND_B), U$3.P$20 (GND_B), U$3.P$26 (GND_A), U$3.P$27 (GND_A), U$3.P$28 (GND_A), U$4.P$18 (GND_B), U$4.P$19 (GND_B), U$4.P$20 (GND_B), U$4.P$26 (GND_A), U$4.P$27 (GND_A), U$4.P$28 (GND_A), U$5.P$18 (GND_B), U$5.P$19 (GND_B), U$5.P$20 (GND_B), U$5.P$26 (GND_A), U$5.P$27 (GND_A), U$5.P$28 (GND_A), U$6.P$18 (GND_B), U$6.P$19 (GND_B), U$6.P$20 (GND_B), U$6.P$26 (GND_A), U$6.P$27 (GND_A), U$6.P$28 (GND_A), U$7.P$18 (GND_B), U$7.P$19 (GND_B), U$7.P$20 (GND_B), U$7.P$26 (GND_A), U$7.P$27 (GND_A), U$7.P$28 (GND_A); also elsewhere on the board
IN0A: IC1.4 (A2); also elsewhere on the board
IN0B: IC1.8 (A4); also elsewhere on the board
IN1A: IC1.13 (A2); also elsewhere on the board
IN1B: IC1.17 (A4); also elsewhere on the board
IN2A: IC2.4 (A2); also elsewhere on the board
IN2B: IC2.8 (A4); also elsewhere on the board
IN3A: IC2.13 (A2); also elsewhere on the board
IN3B: IC2.17 (A4); also elsewhere on the board
IN4A: IC3.4 (A2); also elsewhere on the board
IN4B: IC3.8 (A4); also elsewhere on the board
IN5A: IC3.13 (A2); also elsewhere on the board
IN5B: IC3.17 (A4); also elsewhere on the board
unnamed: R1.2, U$2.P$6 (DIAG_EN_A)
unnamed: R1.1, R5.1, R6.2, R7.2
unnamed: IC1.18 (Y1), R7.1
unnamed: IC1.16 (Y2), R2.1
unnamed: IC1.14 (Y3), R3.1
unnamed: IC1.12 (Y4), R4.1
unnamed: R2.2, U$2.P$5 (IN_A)
unnamed: R3.2, U$2.P$8 (PWM)
unnamed: R4.2, U$2.P$11 (IN_B)
unnamed: R5.2, U$2.P$10 (DIAG_EN_B)
unnamed: R8.2, U$3.P$6 (DIAG_EN_A)
unnamed: R8.1, R12.1, R13.2, R14.2
unnamed: IC1.9 (Y1), R14.1
unnamed: IC1.7 (Y2), R9.1
unnamed: IC1.5 (Y3), R10.1
unnamed: IC1.3 (Y4), R11.1
unnamed: R39.2, U$7.P$11 (IN_B)
unnamed: R38.2, U$7.P$8 (PWM)
unnamed: R37.2, U$7.P$5 (IN_A)
unnamed: R40.2, U$7.P$10 (DIAG_EN_B)
unnamed: R15.2, U$4.P$6 (DIAG_EN_A)
unnamed: R15.1, R19.1, R20.2, R21.2
unnamed: IC2.18 (Y1), R21.1
unnamed: IC2.16 (Y2), R16.1
unnamed: IC2.14 (Y3), R17.1
unnamed: IC2.12 (Y4), R18.1
unnamed: R12.2, U$3.P$10 (DIAG_EN_B)
unnamed: R11.2, U$3.P$11 (IN_B)
unnamed: R16.2, U$4.P$5 (IN_A)
unnamed: R17.2, U$4.P$8 (PWM)
unnamed: R18.2, U$4.P$11 (IN_B)
unnamed: R19.2, U$4.P$10 (DIAG_EN_B)
unnamed: R22.2, U$5.P$6 (DIAG_EN_A)
unnamed: R22.1, R26.1, R27.2, R28.2
unnamed: IC2.9 (Y1), R28.1
unnamed: IC2.7 (Y2), R23.1
unnamed: IC2.5 (Y3), R24.1
unnamed: IC2.3 (Y4), R25.1
unnamed: R10.2, U$3.P$8 (PWM)
unnamed: R9.2, U$3.P$5 (IN_A)
unnamed: R29.2, U$6.P$6 (DIAG_EN_A)
unnamed: R29.1, R33.1, R34.2, R35.2
unnamed: IC3.18 (Y1), R35.1
unnamed: IC3.16 (Y2), R30.1
unnamed: IC3.14 (Y3), R31.1
unnamed: IC3.12 (Y4), R32.1
unnamed: R26.2, U$5.P$10 (DIAG_EN_B)
unnamed: R25.2, U$5.P$11 (IN_B)
unnamed: R30.2, U$6.P$5 (IN_A)
unnamed: R31.2, U$6.P$8 (PWM)
unnamed: R32.2, U$6.P$11 (IN_B)
unnamed: R33.2, U$6.P$10 (DIAG_EN_B)
unnamed: R36.2, U$7.P$6 (DIAG_EN_A)
unnamed: R36.1, R40.1, R41.2, R42.2
unnamed: IC3.9 (Y1), R42.1
unnamed: IC3.7 (Y2), R37.1
unnamed: IC3.5 (Y3), R38.1
unnamed: IC3.3 (Y4), R39.1
unnamed: R24.2, U$5.P$8 (PWM)
unnamed: R23.2, U$5.P$5 (IN_A)
OUT0A: U$2.P$1 (OUT_A), U$2.P$25 (OUT_A), U$2.P$30 (OUT_A), U$2.T$1 (OUT_A); also elsewhere on the board
OUT0B: U$2.P$15 (OUT_B), U$2.P$16 (OUT_B), U$2.P$21 (OUT_B), U$2.T$2 (OUT_B); also elsewhere on the board
OUT1A: U$3.P$1 (OUT_A), U$3.P$25 (OUT_A), U$3.P$30 (OUT_A), U$3.T$1 (OUT_A); also elsewhere on the board
OUT1B: U$3.P$15 (OUT_B), U$3.P$16 (OUT_B), U$3.P$21 (OUT_B), U$3.T$2 (OUT_B); also elsewhere on the board
OUT2A: U$4.P$1 (OUT_A), U$4.P$25 (OUT_A), U$4.P$30 (OUT_A), U$4.T$1 (OUT_A); also elsewhere on the board
OUT2B: U$4.P$15 (OUT_B), U$4.P$16 (OUT_B), U$4.P$21 (OUT_B), U$4.T$2 (OUT_B); also elsewhere on the board
OUT3A: U$5.P$1 (OUT_A), U$5.P$25 (OUT_A), U$5.P$30 (OUT_A), U$5.T$1 (OUT_A); also elsewhere on the board
OUT3B: U$5.P$15 (OUT_B), U$5.P$16 (OUT_B), U$5.P$21 (OUT_B), U$5.T$2 (OUT_B); also elsewhere on the board
OUT4A: U$6.P$1 (OUT_A), U$6.P$25 (OUT_A), U$6.P$30 (OUT_A), U$6.T$1 (OUT_A); also elsewhere on the board
OUT4B: U$6.P$15 (OUT_B), U$6.P$16 (OUT_B), U$6.P$21 (OUT_B), U$6.T$2 (OUT_B); also elsewhere on the board
OUT5A: U$7.P$1 (OUT_A), U$7.P$25 (OUT_A), U$7.P$30 (OUT_A), U$7.T$1 (OUT_A); also elsewhere on the board
OUT5B: U$7.P$15 (OUT_B), U$7.P$16 (OUT_B), U$7.P$21 (OUT_B), U$7.T$2 (OUT_B); also elsewhere on the board
PWM0: IC1.6 (A3); also elsewhere on the board
PWM1: IC1.15 (A3); also elsewhere on the board
PWM2: IC2.6 (A3); also elsewhere on the board
PWM3: IC2.15 (A3); also elsewhere on the board
PWM4: IC3.6 (A3); also elsewhere on the board
PWM5: IC3.15 (A3); also elsewhere on the board
VCC: C1.1, C2.1, C3.1, IC1.20 (VCC), IC2.20 (VCC), IC3.20 (VCC), R6.1, R13.1, R20.1, R27.1, R34.1, R41.1; also elsewhere on the board

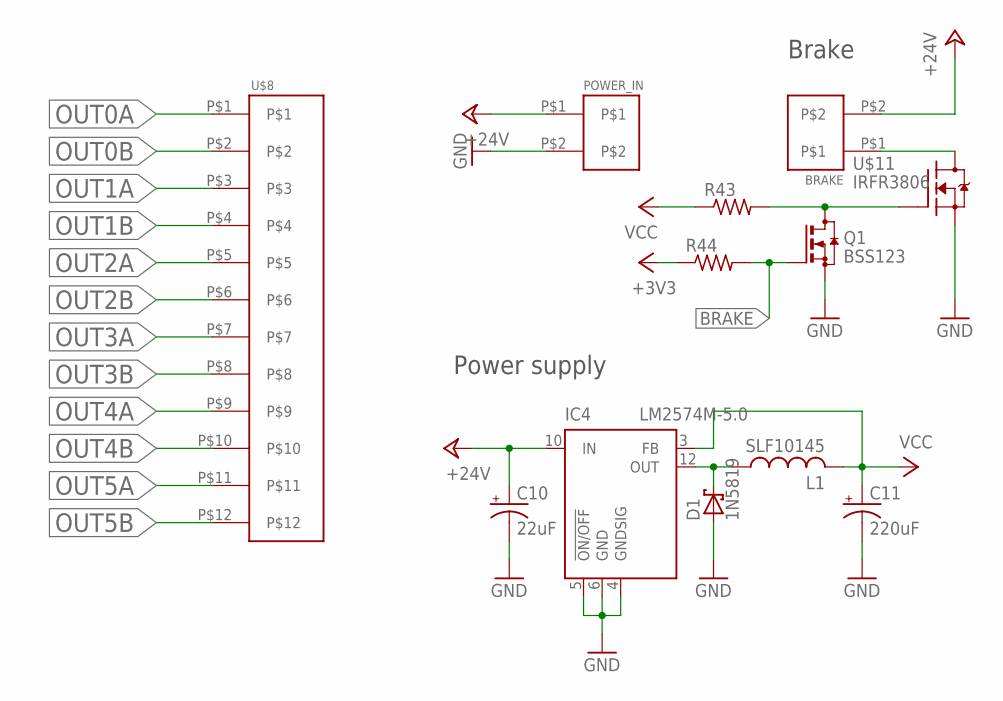
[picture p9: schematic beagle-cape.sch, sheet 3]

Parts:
BRAKE: PINHEAD-5MM-1X2; 5MM-HEADER-2
C10: 22uF; SANYO-OSCON_SMD_E7
C11: 220uF; SANYO-OSCON_SMD_F8
D1: 1N5819; SOD-123
IC4: LM2574M-5.0; SO14W
L1: SLF10145; SMD10145
POWER_IN: PINHEAD-5MM-1X2; 5MM-HEADER-2
Q1: BSS123; SOT23
R43, R44: R-US_R1206; R1206
U$8: PINHEAD-0.2IN-1X12; 0.2IN-TERMINAL-BLOCK-12
U$11: IRFR3806; TO252

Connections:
+3V3: R44.1; also elsewhere on the board
+24V: BRAKE.P$2, C10.+, IC4.10 (IN), POWER_IN.P$1; also elsewhere on the board
BRAKE: Q1.1 (G), R44.2; also elsewhere on the board
GND: C10.-, C11.-, D1.A, IC4.4 (GNDSIG), IC4.5 (!ON/OFF), IC4.6 (GND), POWER_IN.P$2, Q1.2 (S), U$11.2 (S); also elsewhere on the board
unnamed: D1.C, IC4.12 (OUT), L1.P$1 (1)
unnamed: BRAKE.P$1, U$11.3 (D)
unnamed: Q1.3 (D), R43.2, U$11.1 (G)
OUT0A: U$8.P$1; also elsewhere on the board
OUT0B: U$8.P$2; also elsewhere on the board
OUT1A: U$8.P$3; also elsewhere on the board
OUT1B: U$8.P$4; also elsewhere on the board
OUT2A: U$8.P$5; also elsewhere on the board
OUT2B: U$8.P$6; also elsewhere on the board
OUT3A: U$8.P$7; also elsewhere on the board
OUT3B: U$8.P$8; also elsewhere on the board
OUT4A: U$8.P$9; also elsewhere on the board
OUT4B: U$8.P$10; also elsewhere on the board
OUT5A: U$8.P$11; also elsewhere on the board
OUT5B: U$8.P$12; also elsewhere on the board
VCC: C11.+, IC4.3 (FB), L1.P$2 (2), R43.1; also elsewhere on the board

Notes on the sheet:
Power supply
Brake

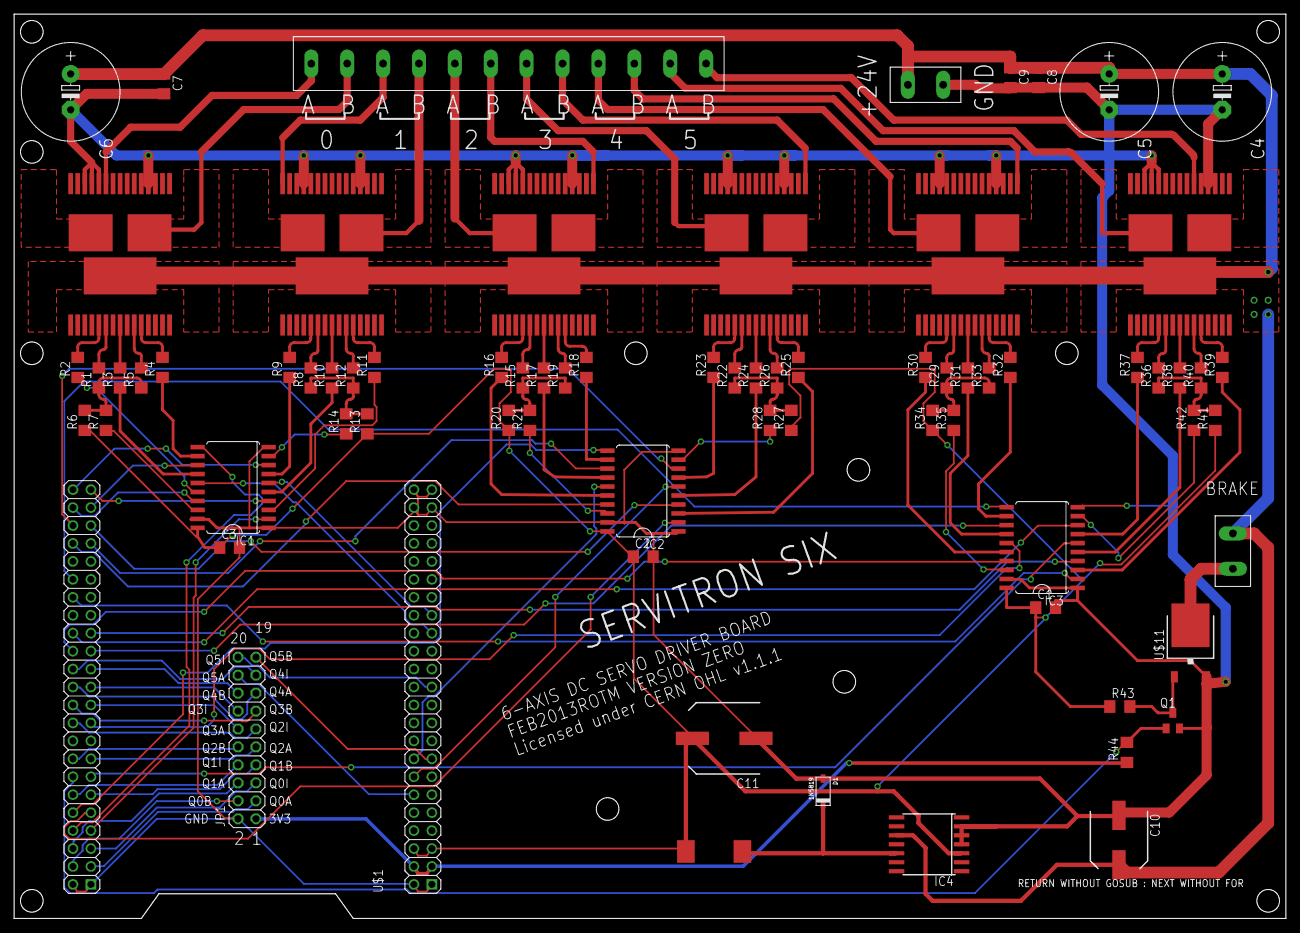
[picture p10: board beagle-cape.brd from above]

Board: 2 copper layers, 180.0 x 128.0 mm, 74 parts (0 on the bottom side), 122 nets.

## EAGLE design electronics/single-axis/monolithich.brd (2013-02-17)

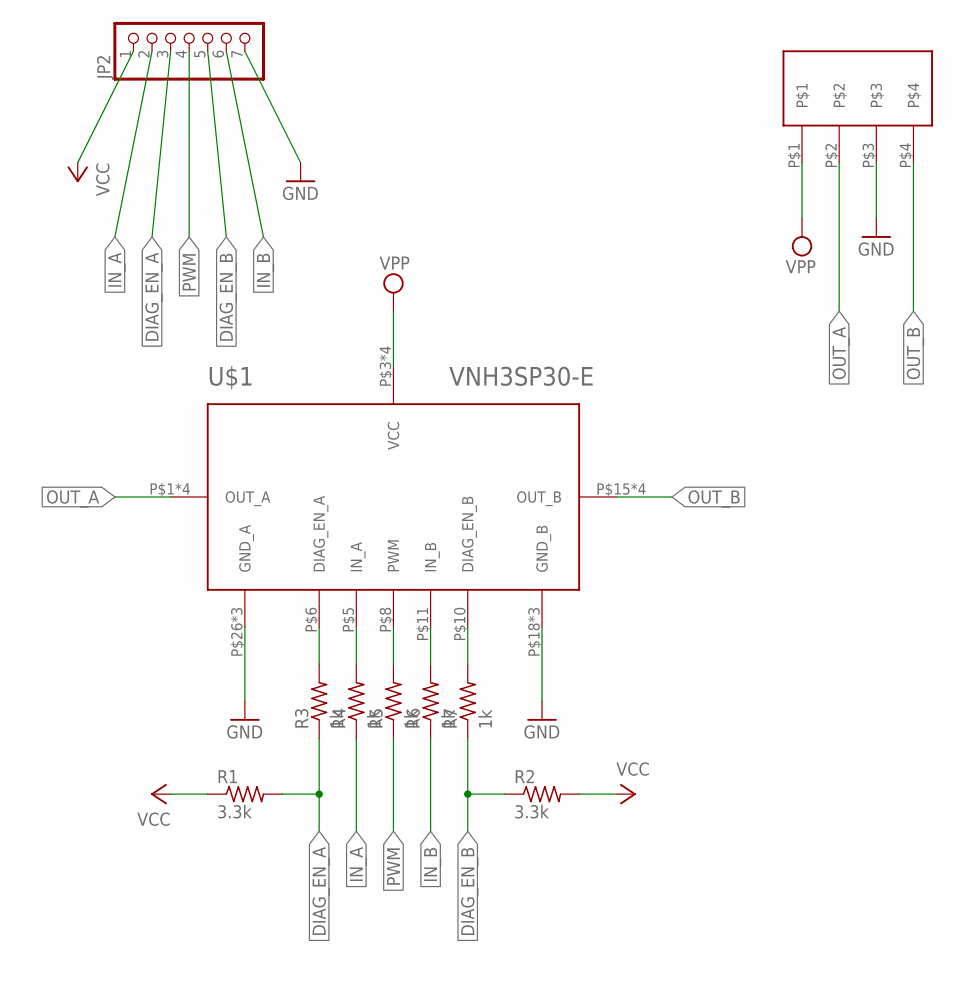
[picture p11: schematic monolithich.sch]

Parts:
JP2: PINHD-1X7; 1X07
R1, R2: 3.3k; R1206
R3, R4, R5, R6, R7: 1k; R1206
U$1: VNH3SP30-E; MULTIPOWER-SO-30
U$2: PINHEAD-5MM-1X4; 5MM-HEADER-4

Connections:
DIAG_EN_A: JP2.3, R1.2, R3.1
DIAG_EN_B: JP2.5, R2.1, R7.1
GND: JP2.7, U$1.P$18 (GND_B), U$1.P$19 (GND_B), U$1.P$20 (GND_B), U$1.P$26 (GND_A), U$1.P$27 (GND_A), U$1.P$28 (GND_A), U$2.P$3
IN_A: JP2.2, R4.1
IN_B: JP2.6, R6.1
unnamed: R3.2, U$1.P$6 (DIAG_EN_A)
unnamed: R4.2, U$1.P$5 (IN_A)
unnamed: R5.2, U$1.P$8 (PWM)
unnamed: R6.2, U$1.P$11 (IN_B)
unnamed: R7.2, U$1.P$10 (DIAG_EN_B)
OUT_A: U$1.P$1 (OUT_A), U$1.P$25 (OUT_A), U$1.P$30 (OUT_A), U$1.T$1 (OUT_A), U$2.P$2
OUT_B: U$1.P$15 (OUT_B), U$1.P$16 (OUT_B), U$1.P$21 (OUT_B), U$1.T$2 (OUT_B), U$2.P$4
PWM: JP2.4, R5.1
VCC: JP2.1, R1.1, R2.2
VPP: U$1.P$3 (VCC), U$1.P$13 (VCC), U$1.P$23 (VCC), U$1.T$3 (VCC), U$2.P$1

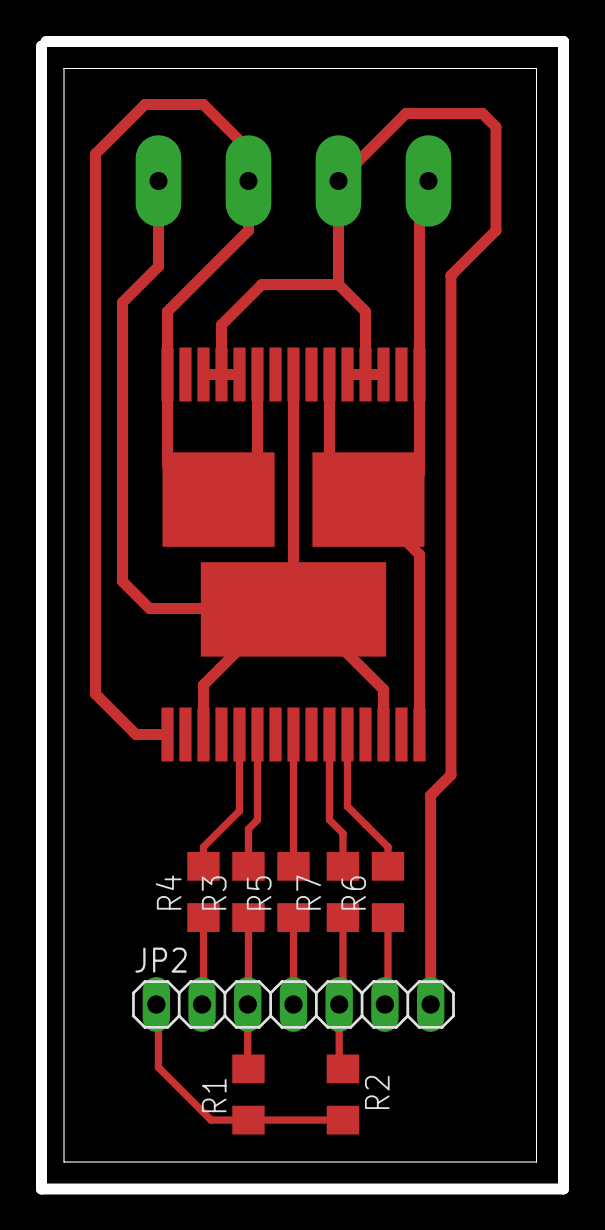
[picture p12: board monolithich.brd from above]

Board: 2 copper layers, 26.2 x 60.8 mm, 10 parts (0 on the bottom side), 15 nets.

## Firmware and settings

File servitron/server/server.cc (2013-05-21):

#include <sys/types.h>
#include <sys/socket.h>
#include <sys/un.h>
#include <errno.h>
#include <unistd.h>

#include <string.h>
#include <iostream>

#include "../include/servitron_cmd.h"
#include "pinmux.h"
#include "motor.h"

using namespace std;
using namespace servitron;

#ifndef SOCKET_NAME
#define SOCKET_NAME "/var/run/servotron"
#endif

#ifndef SERVER_VERSION
#define SERVER_VERSION 0x0001
#endif

#ifndef SERVER_MESSAGE
#define SERVER_MESSAGE "Servitron server debug build"
#endif

const char* socket_name = SOCKET_NAME;
const uint16_t server_version = SERVER_VERSION;
const std::string server_msg(SERVER_MESSAGE);

bool processCommand(int sock);

void init() {
  // Start up backend magic
  mux::mux_all_pins();
  motor::init();
}

void shutdown() {
  motor::shutdown();
}

int startSocketServer(const char* sockName) {
  unsigned int listenSock = socket(AF_UNIX, SOCK_STREAM, 0);
  struct sockaddr_un listenSockaddr;
  listenSockaddr.sun_family = AF_UNIX;
  // Set up abstract socket namespace; Linux-only but saves us from
  // mucking around with unlink() and multiple servers running
  // simultaneously.
  strcpy(listenSockaddr.sun_path+1,sockName);
  listenSockaddr.sun_path[0]='\0';
  size_t len = sizeof(listenSockaddr.sun_family) + 1 + strlen(sockName);
  if (bind(listenSock, (struct sockaddr*)&listenSockaddr, len) == -1) {
    cerr << "Could not bind " << sockName << ": " <<strerror(errno) <<endl;
    return -1;
  }
  if (listen(listenSock,2) == -1) {
    cerr << "Could not listen on " << sockName << ": " <<strerror(errno) <<endl;
    return -1;
  }
  while(1) {
    // Accept one client at a time.
    struct sockaddr_un inSockaddr;
    socklen_t len = sizeof(inSockaddr);
    int inSock = accept(listenSock, (struct sockaddr*)&inSockaddr, &len);
    if (inSock == -1) {
      cerr << "Bad accept on " << sockName << ": " <<strerror(errno) <<endl;
    } else {
      while(processCommand(inSock));
      close(inSock);
    }
  }
  return 0;
}

// FIXME: limited-length buffer!
std::string recvNTStr(int sock) {
  const size_t buflen = 256;
  char buf[buflen];
  size_t idx = 0;
  char c;
  while (recv(sock, &c, 1, 0) == 1 && c != '\0') {
    buf[idx++] = c;
    if (idx >= buflen) { idx = buflen - 1; }
  }
  buf[idx] = 0;
  return string(buf);
}

void sendNTStr(int sock, const std::string& s) {
  send(sock, s.c_str(), s.size(), 0);
  const char null = 0;
  send(sock, &null, 1, 0);
}

bool handleHello(int sock) {
  uint16_t clientVersion;
  recv(sock,&clientVersion,sizeof(clientVersion),0);
  std::string s = recvNTStr(sock);
  cout << "Got hello from version "<<clientVersion<<", message "<<s<<endl;
  send(sock,&RspOK,1,0);
  send(sock,&server_version,sizeof(server_version),0);
  sendNTStr(sock,server_msg);
  return true;
}

bool handleMechStatus(int sock) {
  MechStatusRsp rsp;
  // Fill mechanical status response
  for (int i =0; i < 6; i++) {
    rsp.axis[i].position = i;
    rsp.axis[i].velocity = -i;
    rsp.axis[i].flags = 100;
  }
  send(sock,&RspOK,1,0);
  send(sock,&rsp,sizeof(rsp),0);
  return true;
}

bool handleQueueStatus(int sock) {
  QueueStatusRsp rsp;
  // Fill queue status response
  rsp.remainingMoves = 0;
  send(sock,&RspOK,1,0);
  send(sock,&rsp,sizeof(rsp),0);
  return true;
}

bool processCommand(int sock) {
  uint8_t cmd;
  ssize_t sz = recv(sock, &cmd, 1, 0);
  if (sz == 1) {
    // process command
    switch(cmd) {
    case Hello:
      return handleHello(sock);
    case MechStatus:
      return handleMechStatus(sock);
    case QueueStatus:
      return handleQueueStatus(sock);
    default:
      break;
    }
  } else {
    return false; // orderly shutdown or error
  }
  return true;
}

int main(int argc, char*argv[]) {
  init();
  int rv = startSocketServer(socket_name);
  shutdown();
  return rv;
}

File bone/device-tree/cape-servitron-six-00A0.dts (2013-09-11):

/dts-v1/;
/plugin/;

/ {
    compatible = "ti,beaglebone-black";

    /* identification */
    part-number = "BB-SERVITRON-SIX";
    version = "00A0";
    dtbo = "cape-servitron-00A0.dtbo";

    /* state the resources this cape uses or prepare to get winged! */
    exclusive-use =
        /* Quadrature inputs */
        "P8.7", "P8.8", "P8.9",
        "P8.10", "P8.18", "P8.30",
        "P8.34", "P8.36", "P8.37",
        "P8.38", "P8.39", "P8.40",
        "P8.41", "P8.42", "P8.43",
        "P8.44", "P8.45", "P8.46",
        /* Motor enable (PWM) pins */
        "P9.22",
        "P9.21",
        "P9.14",
        "P9.16",
        "P8.19",
        "P8.13",
        /* Enable and direction pins */
        "P8.35", // M_EN (active low)
        "P9.11", "P9.12", "P9.13",
        "P9.15", "P9.17", "P9.18",
        "P9.23", "P9.24", "P9.26",
        "P9.27", "P9.29", "P9.30",
        "P8.12", "P8.14", "P8.16",
        "P8.11", "P8.15", "P8.17",
        /* Brake */
        "P8.33",
        /* Hardware IP cores in use */
        "ehrpwm0A",
        "ehrpwm0B",
        "ehrpwm1A",
        "ehrpwm1B",
        "ehrpwm2A",
        "ehrpwm2B",
        "pruss"; 

    fragment@0 {
        target = <&am33xx_pinmux>;
        __overlay__ {
            pwm0a_pin: pinmux_pwm0a_pin { pinctrl-single,pins = < 0x150 0x3 >; }; // P9.22 - pwm0a - spi0_sclk
            pwm0b_pin: pinmux_pwm0b_pin { pinctrl-single,pins = < 0x154 0x3 >; }; // P9.21 - pwm0b - spi0_d0
            pwm1a_pin: pinmux_pwm1a_pin { pinctrl-single,pins = < 0x048 0x6 >; }; // P9.14 - pwm1a - gpmc_a2
            pwm1b_pin: pinmux_pwm1b_pin { pinctrl-single,pins = < 0x04c 0x6 >; }; // P9.16 - pwm1b - gpmc_a3
            pwm2a_pin: pinmux_pwm2a_pin { pinctrl-single,pins = < 0x020 0x4 >; }; // P8.19 - pwm2a - gpmc_ad8
            pwm2b_pin: pinmux_pwm2b_pin { pinctrl-single,pins = < 0x024 0x4 >; }; // P8.13 - pwm2b - gpmc_ad9
            brake_pins: pinmux_brake_pins{
                pinctrl-single,pins = <
                    // Mode is 0x0f: input off, pullup off
                    0x0d4 0xf // P8.33 - BRAKE - lcd_data13     GPIO0_9
                >;
            };
            motor_pins: pinmux_motor_pins{
                pinctrl-single,pins = <
                    // Mode is 0x0f: input off, pullup off
                    0x0d0 0xf // P8.35 - M_EN - lcd_data12      GPIO0_8
                    // M0
                    0x15c 0xf // P9.17 - M0_A  - spi0_cs0       GPIO0_5
                    0x040 0xf // P9.15 - M0_B  - gpmc_a0        GPIO1_16
                    0x158 0xf // P9.18 - M0_EN - spi0_d1        GPIO0_4
                    // M1
                    0x074 0xf // P9.13 - M1_A  - gpmc_wpn       GPIO0_31
                    0x070 0xf // P9.11 - M1_B  - gpmc_wait0     GPIO0_30
                    0x078 0xf // P9.12 - M1_EN - gpmc_ben1      GPIO1_28
                    // M2
                    0x180 0xf // P9.26 - M2_A  - uart1_rxd      GPIO0_14
                    0x184 0xf // P9.24 - M2_B  - uart1_txd      GPIO0_15
                    0x198 0xf // P9.30 - M2_EN - mcasp0_axr0    GPIO3_16
                    // M3
                    0x1a4 0xf // P9.27 - M3_A  - mcasp0_fsr     GPIO3_19
                    0x044 0xf // P9.23 - M3_B  - gpmc_a1        GPIO1_17
                    0x194 0xf // P9.29 - M3_EN - mcasp0_fsx     GPIO3_15
                    // M4
                    0x038 0xf // P8.16 - M4_A  - gpmc_ad14      GPIO1_14
                    0x028 0xf // P8.14 - M4_B  - gpmc_ad10      GPIO0_26
                    0x030 0xf // P8.12 - M4_EN - gpmc_ad12      GPIO1_12
                    // M5
                    0x034 0xf // P8.11 - M5_A  - gpmc_ad13      GPIO1_13
                    0x03c 0xf // P8.15 - M5_B  - gpmc_ad15      GPIO1_15
                    0x02c 0xf // P8.17 - M5_EN - gpmc_ad11      GPIO0_27
                >;
            };
            pruicss_quad_pins: pinmux_pruicss_quad_pins{
                pinctrl-single,pins = <
                    // Mode is 0x3f: input turned on, pullup off
                    0x090 0x3f // P8.7  - Q0A - gpmc_advn_ale   GPIO2_2
                    0x094 0x3f // P8.8  - Q0B - gpmc_oen_ren    GPIO2_3
                    0x09c 0x3f // P8.9  - Q0I - gpmc_ben0_cle   GPIO2_5

                    0x098 0x3f // P8.10 - Q1A - gpmc_wen        GPIO2_4
                    0x08c 0x3f // P8.18 - Q1B - gpmc_clk        GPIO2_1
                    0x0ec 0x3f // P8.30 - Q1I - lcd_ac_bias_en  GPIO2_25

                    0x0cc 0x3f // P8.34 - Q2A - lcd_data_11     GPIO2_17
                    0x0c8 0x3f // P8.36 - Q2B - lcd_data_10     GPIO2_16
                    0x0c0 0x3f // P8.37 - Q2I - lcd_data_8      GPIO2_14

                    0x0c4 0x3f // P8.38 - Q3A - lcd_data_9      GPIO2_15
                    0x0b8 0x3f // P8.39 - Q3B - lcd_data_6      GPIO2_12
                    0x0bc 0x3f // P8.40 - Q3I - lcd_data_7      GPIO2_13

                    0x0b0 0x3f // P8.41 - Q4A - lcd_data_4      GPIO2_10
                    0x0b4 0x3f // P8.42 - Q4B - lcd_data_5      GPIO2_11
                    0x0a8 0x3f // P8.43 - Q4I - lcd_data_2      GPIO2_8

                    0x0ac 0x3f // P8.44 - Q5A - lcd_data_3      GPIO2_9
                    0x0a0 0x3f // P8.45 - Q5B - lcd_data_0      GPIO2_6
                    0x0a4 0x3f // P8.46 - Q5I - lcd_data_1      GPIO2_7
                >;
            };

        };
    };

    fragment@1{
        target = <&pruss>;
        __overlay__{
            status = "okay";
            pinctrl-names = "default";
            pinctrl-0       = <&pruicss_quad_pins>;

            quad_0{
                pin-names     = "Servi:q0_a", "Servi:q0_b", "Servi:q0_i";
                gpios         = <&gpio3 2 0x5
                                &gpio3 3 0x5
                                &gpio3 5 0x5>; 
            };            

            quad_1{
                pin-names     = "Servi:q1_a", "Servi:q1_b", "Servi:q1_i";
                gpios         = <&gpio3 4 0x5
                                &gpio3 1 0x5
                                &gpio3 25 0x5>; 
            };            

            quad_2{
                pin-names     = "Servi:q2_a", "Servi:q2_b", "Servi:q2_i";
                gpios         = <&gpio3 17 0x5
                                &gpio3 16 0x5
                                &gpio3 14 0x5>; 
            };            

            quad_3{
                pin-names     = "Servi:q3_a", "Servi:q3_b", "Servi:q3_i";
                gpios         = <&gpio3 15 0x5
                                &gpio3 12 0x5
                                &gpio3 13 0x5>; 
            };            

            quad_4{
                pin-names     = "Servi:q4_a", "Servi:q4_b", "Servi:q4_i";
                gpios         = <&gpio3 10 0x5
                                &gpio3 11 0x5
                                &gpio3 8 0x5>; 
            };
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

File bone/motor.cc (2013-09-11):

#include "motor.h"
#include "util.h"
#include "config.h"

const std::string enable_pin = "servitron:m_en";

const std::string pwm_prefix = "/sys/devices/ocp.2/";
const std::string pwm_suffix = "/duty";

class MotorImpl {
private:
  LedOut m_a, m_b, m_en;
  std::ofstream m_duty_stream;
public:
  MotorImpl(const std::string& a,
            const std::string& b,
            const std::string& en,
            const std::string& pwm) :
    m_a(a), m_b(b), m_en(en) {
    m_duty_stream.open((pwm_prefix + pwm + pwm_suffix).c_str());
    m_en.set(0);
  }
  ~MotorImpl() {
    m_duty_stream.close();
  }
  void setPower(float v) {
    if (v>1.0) v=1.0;
    if (v<-1.0) v=-1.0;

    int value = (int)(v * 200000.0);

    m_en.set((value == 0)?0:1);
    
    if (value > 0) {
      m_b.set(0);
      m_a.set(1);
      m_en.set(1);
      m_duty_stream << value << std::endl;
    } else if (value < 0) {
      m_a.set(0);
      m_b.set(1);
      m_en.set(1);
      m_duty_stream << -value << std::endl;
    } else if (value == 0) {
      m_a.set(0);
      m_b.set(0);
      m_en.set(0);
      m_duty_stream << value << std::endl;
    }
  }
};

Motors::Motors() : m_en(enable_pin)
{
  m_impl[0] = new MotorImpl("servitron:m0_a",
                            "servitron:m0_b",
                            "servitron:m0_en",
                            "motor_pwm1b.15");
  m_impl[1] = new MotorImpl("servitron:m1_a",
                            "servitron:m1_b",
                            "servitron:m1_en",
                            "motor_pwm1a.14");
  m_impl[2] = new MotorImpl("servitron:m2_a",
                            "servitron:m2_b",
                            "servitron:m2_en",
                            "motor_pwm0a.12");
  m_impl[3] = new MotorImpl("servitron:m3_a",
                            "servitron:m3_b",
                            "servitron:m3_en",
                            "motor_pwm0b.13");
  m_impl[4] = new MotorImpl("servitron:m4_a",
                            "servitron:m4_b",
                            "servitron:m4_en",
                            "motor_pwm2a.16");
  m_impl[5] = new MotorImpl("servitron:m5_a",
                            "servitron:m5_b",
                            "servitron:m5_en",
                            "motor_pwm2b.17");
  m_en.set(1);
}

Motors::~Motors() {
  enable(false);
  for (int i = 0; i < 6; i++) { 
    m_impl[i]->setPower(0);
    delete m_impl[i]; 
    m_impl[i] = 0; 
  }
}

void Motors::enable(bool en) {
  m_en.set(en?0:1);
}


// Set the motor to the specified
// power. 0 is off. Negative values are CCW, positive
// are CW.
void Motors::setPower(int channel, float value) {
  m_impl[channel]->setPower(value);
}
    

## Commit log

2000-01-01 brake working.
2000-01-01 getting motor tuned
2000-01-01 some sytax fixes to the device tree; appears to work
    [cape-servitron-six-00A0.dts]
2000-01-01 fix: duplicate pinmux names
    [cape-servitron-six-00A0.dts]
2000-01-01 increase power, motor enable
2000-01-01 basic motor enabled
2012-11-22 It's "servItron", not "servotron".
2012-11-22 fix makefile; added retval in init
    [pwm.cc]
2013-02-16 package footprint gen script; library for various parts
2013-02-17 test board for vnh3sp30 driver
    [monolithich.brd, monolithich.sch]
2013-02-19 framework for encoder
2013-02-20 script for driving a vnh3sp30 off a teensy
2013-02-21 roughing out pwm stuff
2013-02-21 fixing up pwm rough
2013-02-21 starting in on proper servo system
2013-02-26 adding rough motor stuff
2013-02-27 motor test
2013-02-27 preparing motor test
2013-02-27 config motors
2013-02-28 refactor motor control
2013-02-28 adding timer to quadrature loop
2013-03-02 adding trivial PID code
2013-03-02 we have a basic control circuit running
2013-03-03 corrected pwm code for 1KHz
    [pwm.cc]
2013-03-10 start on 32->32 multiply moved eagle library start work on complete six-axis servo board
    [beagle-cape.sch]
2013-03-11 added 24V->5V converter, brake circuit
    [beagle-cape.sch]
2013-03-12 schematic capture complete; board time
    [beagle-cape.sch]
2013-03-14 initially laying out by hand
    [beagle-cape.brd, beagle-cape.sch]
2013-03-14 more routing; auto the rest
    [beagle-cape.brd, beagle-cape.sch]
2013-03-14 board layout is pretty much done and doc strings are in. prepping for production.
    [beagle-cape.brd, beagle-cape.sch]
2013-03-14 putting under CERN OHL v1.1.1
    [beagle-cape.brd]
2013-03-15 Added mounting holes Created board files for freedfm/4pcb (ac)
    [beagle-cape.brd]
2013-04-01 adding brake functionality
2013-04-01 brake working with actual board
2013-04-02 adding mounting for servitron six
    [mounting.dxf]
2013-04-23 moving brake test adding readme makefile updated to new pasm build
2013-04-26 removing old encoder test
2013-04-26 moving to top level (removing servo subdir)
2013-04-27 basic waf script for brake test
2013-04-28 updating config (fix for 5/4 pwm switch)
    [servo.cc, servo_test.cc]
2013-05-13 adding simple socket server
2013-05-13 moving in pin configuration and retooling basic server outline running
2013-05-13 update submodule to reflect arm name change
2013-05-17 added missing motor muxes
2013-05-17 starting in on motor/pwm implementation
2013-05-21 fixup server build; init motor and pinmux at startup
    [server.cc]
2013-05-23 keep screwing up the name
2013-07-17 adding initial start on devicetree file
2013-07-18 muxing and assignment for all quadrature encoder pins
2013-07-19 remove unnecessary pin muxes (now done by device tree)
2013-07-19 workaround for 1-indexing in device tree
    [cape-servitron-six-00A0.dts]
2013-07-20 moving pwm stuff in
2013-07-25 initial checkin of new cape
    [cape-servitron-v1.brd, cape-servitron-v1.sch]
2013-07-26 added holes, layout mostly done
    [cape-servitron-v1.brd, cape-servitron-v1.sch]
2013-07-27 added more heat sinking
    [cape-servitron-v1.brd]
2013-08-01 board sent out; cleaning up quadrature assembly
    [cape-servitron-v1.brd]
2013-08-10 renamed chips and output signals to match board placement and markings
    [cape-servitron-v1.brd, cape-servitron-v1.sch]
2013-08-10 updated signals for current layout
    [cape-servitron-v1.brd, cape-servitron-v1.sch]
2013-09-03 moving brake code around; adding brake to device tree as led
2013-09-03 adding motor muxing and pin selection
2013-09-09 enabling pwm_test
2013-09-10 updating brake code
2013-09-10 adding motor control logic
2013-09-10 adding motor tests
2013-09-10 adding brake to motor test
2013-09-10 removed obsolete pwm
2013-09-10 adding brake dep to motor test
2013-09-11 moving motors to float values

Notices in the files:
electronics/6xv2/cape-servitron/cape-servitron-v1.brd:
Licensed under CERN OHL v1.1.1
